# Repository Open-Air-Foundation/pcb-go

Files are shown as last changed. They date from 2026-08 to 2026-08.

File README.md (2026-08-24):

# AirGradient GO — Hardware

> KiCad hardware design files for the AirGradient GO, a portable battery-powered air quality monitor.

<!-- ![AirGradient GO](graphics/airgradient Final-02.png) -->

## Overview

AirGradient GO is a handheld air quality monitor. It measures particulate matter (Sensirion SPS30), CO₂ (Senseair S12), VOC/NOx (SGP41), temperature and humidity (SHT4x), and barometric pressure (DPS368), with an accelerometer (LIS2DH12) for motion detection and a GPS receiver (TAU1113) for location. Readings are shown on a 2.13″ black-and-white e-paper display with RGB LED indicators and capacitive touch controls. The device runs on a 505060 Li-Po pouch cell charged over USB-C.

This repository contains the complete electronics design: schematics, PCB layouts, shared component libraries, and production outputs for all four boards.

## Boards in this repository

| Board | Directory | Latest production set | Layers | Description |
|---|---|---|---|---|
| Main board | `PCB/airgradient-go-main/` | v1.0 | 4 | MCU, power/charging, sensors, storage |
| LED + touch controller | `PCB/led-touch/` | AG-GO-LED v1.0 | 2 | RGB LEDs, LED driver, and capacitive-touch controller; mates with the touch-pad board and mechanically holds the e-paper display (the display connector and control circuitry are on the main board) |
| Touch pad | `PCB/touch-pad/` | Touch_sensor v1.0 | 2 | Capacitive touch input board |
| SCD4x module | `PCB/scd4x-module/` | v0.1 | 2 | Optional CO₂ daughterboard (the standard configuration uses the on-board Senseair S12) |

> **Note:** v2.0 of the main board, touch pad, and LED + touch boards is currently in development.

## Key components (main board)

| Function | Part | Ref |
|---|---|---|
| MCU / Wi-Fi | ESP32-C5-MINI-1 | U4 |
| Battery charger | BQ25628 | U3 |
| Fuel gauge | BQ27427 | U8 |
| Buck-boost converter | TPS63802 | U2 |
| LDO | TPS7A0228 | U7 |
| Hardware watchdog | TPL5010 | U5 |
| NAND flash (512 Mb) | W25N512GVEIG | U1 |
| NAND flash (alternative footprint for U1) | ZDSD512MLGEAG | U14 |
| CO₂ sensor module | Senseair S12 | U17 |
| VOC/NOx sensor | SGP41 | U9 |
| Temperature/humidity sensor | SHT4x | U13 |
| Pressure sensor | DPS368 | U15 |
| Accelerometer | LIS2DH12 | U11 |
| GPS receiver | TAU1113 | U16 |
| I²C bus isolator | TMUX121 | U10 |
| I/O expander | TCA9536 | U18 |
| Buzzer | HYG-8503A | U12 |
| GPS antenna | GPS1003 | ANT1 |
| USB-C connector | GT-USB-7010ASV | USB1 |

PM sensing uses a Sensirion SPS30 module connected to the main board. CO₂ sensing is handled by the on-board Senseair S12; the SCD4x daughterboard is an optional alternative.

## Toolchain

- **KiCad 10** (file format 2026-03). All symbol, footprint, and 3D model libraries are bundled in `libraries/` and referenced project-relative through each board's `fp-lib-table` / `sym-lib-table` — the projects open without any extra library setup.
- **[Fabrication Toolkit](https://github.com/bennymeg/Fabrication-Toolkit)** plugin — generates the Gerber/BOM/CPL production sets (`fabrication-toolkit-options.json` per board).

## Repository structure

```
PCB/
├── airgradient-go-main/     # Main PCB (schematic, layout, production/)
├── led-touch/               # LED + touch-controller PCB (also holds the e-paper display)
├── touch-pad/               # Capacitive touch PCB
└── scd4x-module/            # Optional SCD4x CO₂ daughterboard
libraries/                   # Shared KiCad symbols, footprints, 3D models
graphics/                    # Logos and artwork
```

## Fabrication

Each board's `production/` directory holds the ready-to-order set for its latest released version: Gerber zip, BOM, designators, and pick-and-place positions in JLCPCB-compatible format (generated with Fabrication Toolkit). The main board is a 4-layer design; the display, touch, and SCD4x boards are 2-layer.

## BOM & sourcing

BOMs are exported alongside each production set (`production/*_bom.csv`) with LCSC part numbers for assembly at JLCPCB.

## Versioning & releases

Hardware revisions are tagged on this repository. Per-version release notes — chip-level changes, design history, and the matching production file set — are published on the [GitHub Releases](../../releases) page.

## Related repositories

<!-- TODO: add links to the firmware and enclosure repositories -->

## License

This is open-source hardware. The design files in this repository are licensed under the
[Creative Commons Attribution-ShareAlike 4.0 International (CC BY-SA 4.0)](https://creativecommons.org/licenses/by-sa/4.0/) license — see [LICENSE](LICENSE).

You are free to use, modify, and manufacture these designs, including commercially, provided you credit AirGradient and share derivative designs under the same license.

## Maintainers

AirGradient hardware team.

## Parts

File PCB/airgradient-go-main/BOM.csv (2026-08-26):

Reference | Qty | Value | DNP | Exclude from BOM | Exclude from Board | Footprint | Datasheet | LCSC Part
BT1 | 1 | Battery_Cell |  |  |  | AG-lib-oaf:AGGO-battery
C1,C3,C5,C7,C9,C10,C13,C15,C16,C24,C28,C39,C52,C56,C57,C59,C63,C70,C71,C72,C73,C74 | 22 | 0.1uF/25V |  |  |  | Capacitor_SMD:C_0402_1005Metric | https://lcsc.com/product-detail/Multilayer-Ceramic-Capacitors-MLCC-SMD-SMT_SAMSUNG_CL05A104KA5NNNC_100nF-104-10-25V_C100072.html | C100072
C2 | 1 | 47nF/25V |  |  |  | Capacitor_SMD:C_0402_1005Metric | https://lcsc.com/product-detail/Others_Guangdong-Fenghua-Advanced-Tech-0402B473K250NT_C285062.html | C285062
C4,C6,C11,C22,C60,C65 | 6 | 10uF/25V |  |  |  | Capacitor_SMD:C_0603_1608Metric | https://lcsc.com/product-detail/Multilayer-Ceramic-Capacitors-MLCC-SMD-SMT_SAMSUNG_CL10A106MA8NRNC_10uF-106-20-25V_C96446.html | C96446
C8,C45,C48 | 3 | 4.7uF/25V |  |  |  | Capacitor_SMD:C_0402_1005Metric |  | C6119795
C12,C36,C37,C38 | 4 | 22uF/25V |  |  |  | Capacitor_SMD:C_0805_2012Metric | https://lcsc.com/product-detail/Multilayer-Ceramic-Capacitors-MLCC-SMD-SMT_Samsung-Electro-Mechanics-CL21A226MAYNNNE_C602037.html | C602037
C17 | 1 | 0.1uF/10V |  |  |  | Capacitor_SMD:C_0402_1005Metric | https://lcsc.com | C315248
C19,C26,C29,C30,C35,C40,C41,C42,C43,C44,C46,C47,C49,C50,C51,C53,C54,C55,C58,C64,C66,C67,C68 | 23 | 1uF/50V |  |  |  | Capacitor_SMD:C_0402_1005Metric | https://lcsc.com/product-detail/Multilayer-Ceramic-Capacitors-MLCC-SMD-SMT_SAMSUNG_CL05A105KO5NNNC_1uF-105-10-16V_C29266.html | C7500380
C20 | 1 | 47uF/25V |  |  |  | Capacitor_SMD:C_1206_3216Metric | https://lcsc.com/product-detail/Multilayer-Ceramic-Capacitors-MLCC-SMD-SMT_Murata-Electronics-GRM31CR61E476ME44L_C403725.html | C403725
C21 | 1 | 22uF/10V |  |  |  | Capacitor_SMD:C_0402_1005Metric | https://lcsc.com | C315248
C27 | 1 | 0.47uF/25V |  |  |  | Capacitor_SMD:C_0402_1005Metric | https://lcsc.com/product-detail/Multilayer-Ceramic-Capacitors-MLCC-SMD-SMT_SAMSUNG_CL05A105KO5NNNC_1uF-105-10-16V_C29266.html | C7500380
C33 | 1 | 500pF/50V |  |  |  | Capacitor_SMD:C_0603_1608Metric | https://lcsc.com/product-detail/Multilayer-Ceramic-Capacitors-MLCC-SMD-SMT_500pF-501-10-50V_C1624.html | C1624
C69 | 1 | 0.1uF/16V |  |  |  | Capacitor_SMD:C_0402_1005Metric | https://lcsc.com/product-detail/Multilayer-Ceramic-Capacitors-MLCC-SMD-SMT_SAMSUNG_CL05B104KO5NNNC_100nF-104-10-16V_C1525.html | C1525
CN3,CN4,CN5 | 3 | SM05B-SRSS-TB (LF)(SN) |  |  |  | easyeda2kicad-oaf:CONN-SMD_SM05B-SRSS-TB-LF-SN | https://lcsc.com/product-detail/Connectors_JST_SM05B-SRSS-TB-LF-SN_SM05B-SRSS-TB-LF-SN_C136657.html | C136657
D3,D4,D5 | 3 | PMEG3005EL,315 |  |  |  | easyeda2kicad-oaf:SOD-882_L1.0-W0.6-RD | https://lcsc.com/product-detail/Schottky-Barrier-Diodes-SBD_Nexperia_PMEG3005EL-315_Nexperia-PMEG3005EL-315_C282565.html | C282565
F1 | 1 | BSMD1206-075-6V |  |  |  | easyeda2kicad-oaf:F1206 | https://lcsc.com/product-detail/PTC-Resettable-Fuses_BHFUSE-BSMD1206-075-6V_C883127.html | C883127
FPC1 | 1 | FPC 0.5-24P LTH2.0 |  |  |  | easyeda2kicad-oaf:FPC-SMD_FPC-0.5-24P-LTH2.0 |  | C6081230
L1 | 1 | 252012CDMCDDS-1R0MC |  |  |  | easyeda2kicad-oaf:IND-SMD_L2.5-W2.0 | https://lcsc.com/product-detail/New-Arrivals_Sumida-252012CDMCDDS-1R0MC_C492725.html | C492725
L2 | 1 | XGL4020-471MEC |  |  |  | easyeda2kicad-oaf:IND-SMD_L4.0-W4.0_XGL4020 |  | C5837785
L3 | 1 | XRTC201210S100MBCA |  |  |  | easyeda2kicad-oaf:L0805 |  | C39846618
LED1,LED2,LED3,LED4 | 4 | TJ-S1608SW6TDSLCCYRGB-A5 |  |  |  | easyeda2kicad-oaf:LED-ARRAY-SMD_4P-L1.6-W0.8-BL-FD |  | C5356078
NTC1 | 1 | KNTC0805/10KF3950 |  |  |  | easyeda2kicad-oaf:R0805 |  | C2892549
NTC2 | 1 | NCP15XH103F03RC |  |  |  | easyeda2kicad-oaf:R0402 | https://lcsc.com/product-detail/NTC-Thermistors_muRata_NCP15XH103F03RC_NTCThermistor-10kR-1_C77131.html | C77131
Q1 | 1 | SIA445EDJ-T1-GE3 |  |  |  | easyeda2kicad-oaf:SC-70-6L_L2.0-W2.0-P0.65-BL | https://lcsc.com/product-detail/MOSFET_VISHAY_SIA445EDJ-T1-GE3_SIA445EDJ-T1-GE3_C144959.html | C144959
Q2 | 1 | ZVN4106FTA_C508255 |  |  |  | easyeda2kicad-oaf:SOT-23-3_L2.9-W1.3-P1.90-LS2.4-BR | https://lcsc.com/product-detail/MOSFET_Diodes-Incorporated-ZVN4106FTA_C508255.html | C508255
Q3 | 1 | CSD83325L |  |  |  | easyeda2kicad-oaf:PICOSTAR-6_L2.2-W1.1-R2-C3-P0.65-BL |  | C2860700
Q4 | 1 | SS8050-G |  |  |  | easyeda2kicad-oaf:SOT-23-3_L2.9-W1.3-P1.90-LS2.4-BR | https://lcsc.com/product-detail/Transistors-NPN-PNP_SS8050-L-120-200_C164886.html | C164886
Q5 | 1 | SI1308EDL |  |  |  | easyeda2kicad-oaf:SOT-323-3_L2.0-W1.3-P1.30-LS2.1-BR |  | C7603347
R1,R2,R3,R4,R14,R29,R31,R33,R38,R39,R40,R44,R46,R59 | 14 | 100K |  |  |  | Resistor_SMD:R_0402_1005Metric | https://lcsc.com/product-detail/Chip-Resistor-Surface-Mount_100KR-1003-1_C60491.html,https://lcsc.com/product-detail/Others_Huaxin-S-T-MR04X1002FTL_C327797.html | C327797,C60491
R5,R12 | 2 | 200R |  |  |  | Resistor_SMD:R_0402_1005Metric
R6,R9 | 2 | 10R |  |  |  | Resistor_SMD:R_0402_1005Metric | https://lcsc.com/product-detail/Chip-Resistor-Surface-Mount_1KR-1001-1_C106235.html | C106235
R7,R11,R49 | 3 | 5.1K |  |  |  | Resistor_SMD:R_0402_1005Metric | https://lcsc.com/product-detail/Chip-Resistor-Surface-Mount_5-1KR-5101-1_C105872.html | C105872
R8 | 1 | 5mR 1%/1W |  |  |  | Resistor_SMD:R_1206_3216Metric
R10,R26,R30,R36,R54,R55,R56,R57,R58 | 9 | 10K |  |  |  | Resistor_SMD:R_0402_1005Metric | https://lcsc.com/product-detail/Others_Huaxin-S-T-MR04X1002FTL_C327797.html | C327797
R13 | 1 | 2K |  |  |  | Resistor_SMD:R_0402_1005Metric | https://lcsc.com/product-detail/Chip-Resistor-Surface-Mount_1KR-1001-1_C106235.html | C106235
R15 | 1 | 15K |  |  |  | Resistor_SMD:R_0402_1005Metric | https://lcsc.com/product-detail/Chip-Resistor-Surface-Mount-UniOhm_15KR-1502-1_C25756.html | C25756
R16 | 1 | 20K |  |  |  | Resistor_SMD:R_0402_1005Metric | https://lcsc.com/product-detail/Chip-Resistor-Surface-Mount_20KR-2002-1_C93942.html | C93942
R17,R20,R23 | 3 | 1K |  |  |  | Resistor_SMD:R_0402_1005Metric | https://lcsc.com/product-detail/Chip-Resistor-Surface-Mount_1KR-1001-1_C106235.html | C106235
R18 | 1 | 4.12K |  |  |  | Resistor_SMD:R_0402_1005Metric | https://lcsc.com/product-detail/Others_YAGEO-RC0402FR-074K12L_C327340.html | C327340
R19 | 1 | 17.33K |  |  |  | Resistor_SMD:R_0402_1005Metric |  | C851231
R21 | 1 | 2.49K |  |  |  | Resistor_SMD:R_0402_1005Metric | https://lcsc.com/product-detail/Chip-Resistor-Surface-Mount-UniOhm_2-49KR-2491-1_C25884.html | C25884
R22 | 1 | 475K |  |  |  | Resistor_SMD:R_0402_1005Metric |  | C5713272
R24 | 1 | 91K |  |  |  | Resistor_SMD:R_0402_1005Metric | https://lcsc.com/product-detail/Others_YAGEO-RC0402FR-0791KL_C327323.html | C327323
R25 | 1 | 51K |  |  |  | Resistor_SMD:R_0402_1005Metric | https://lcsc.com/product-detail/Chip-Resistor-Surface-Mount_51KR-5102-1_C107229.html | C107229
R27,R28,R50,R51,R52,R53 | 6 | 22R |  |  |  | Resistor_SMD:R_0402_1005Metric | https://lcsc.com/product-detail/Chip-Resistor-Surface-Mount_22R-22R0-1_C114765.html | C114765
R32 | 1 | 50mR |  |  |  | Resistor_SMD:R_0805_2012Metric | https://lcsc.com/product-detail/Chip-Resistor-Surface-Mount_0R-0R0-1_C106231.html | C106231
R35 | 1 | 470mR |  |  |  | Resistor_SMD:R_0805_2012Metric | https://lcsc.com/product-detail/Chip-Resistor-Surface-Mount_0R-0R0-1_C106231.html | C106231
R41 | 1 | 4.7R |  |  |  | Resistor_SMD:R_0402_1005Metric |  | C2909356
R42 | 1 | 1M |  |  |  | Resistor_SMD:R_0402_1005Metric | https://lcsc.com/product-detail/Chip-Resistor-Surface-Mount_1MR-1004-1_C138033.html | C138033
R43 | 1 | 2.2R |  |  |  | Resistor_SMD:R_0402_1005Metric | https://lcsc.com/product-detail/Chip-Resistor-Surface-Mount-UniOhm_2-2R-2R20-1_C25101.html | C25101
R45,R47 | 2 | 0R |  |  |  | Resistor_SMD:R_0402_1005Metric | https://lcsc.com/product-detail/Chip-Resistor-Surface-Mount_0R-0R0-1_C106231.html | C106231
SW1,SW2 | 2 | TS-1091C-A1B3-D2 |  |  |  | easyeda2kicad-oaf:KEY-SMD_3P-L5.5-W3.8-P3.00 |  | C2874581
TF1 | 1 | TF-CARD XG8P H1.5 |  |  |  | easyeda2kicad-oaf:TF-SMD_TF-CARD-XG8P-H1.5 |  | C7529392
U1 | 1 | W25N512GVEIG |  |  |  | easyeda2kicad-oaf:WSON-8_L8.0-W6.0-P1.27-TL-1 |  | C3024446
U3 | 1 | BQ27742YZFR-G1 |  |  |  | easyeda2kicad-oaf:DSBGA-15_L2.6-W2.0-R5-C3-P0.50-BL |  | C2842397
U4 | 1 | ESP32-C5-MINI-1 |  |  |  | Esparessif-oaf:ESP32-C5-MINI-1 | https://documentation.espressif.com/esp32-c5-mini-1_datasheet_en.pdf
U5 | 1 | BQ25628RYKR |  |  |  | easyeda2kicad-oaf:WQFN-18_L3.0-W2.5-P0.40-TL |  | C6055599
U6 | 1 | HYG-8503A |  |  |  | easyeda2kicad-oaf:BUZ-SMD_4P-L8.5-W8.5-P8.50-BR |  | C7544813
U7 | 1 | TPL5010DDCR |  |  |  | easyeda2kicad-oaf:SOT-23-6_L2.9-W1.6-P0.95-LS2.8-BR | https://lcsc.com/product-detail/Timer_Texas-Instruments-Texas-Instruments-TPL5010DDCR_C473912.html | C473912
U8 | 1 | TPS63802DLAR |  |  |  | easyeda2kicad-oaf:VSON-10_L3.0-W2.0-P0.50-TL |  | C2845237
U9 | 1 | TPS7A0228DQNR |  |  |  | easyeda2kicad-oaf:X2SON-4_L1.0-W1.0-P0.65-TL-EP |  | C5220175
U13 | 1 | SPL07-003 |  |  |  | easyeda2kicad-oaf:LGA-10_L2.0-W2.0-P0.50-BL |  | C3253727
U14 | 1 | LIS2DH12TR |  |  |  | easyeda2kicad-oaf:LGA-12_L2.0-W2.0-P0.50-BL | https://lcsc.com/product-detail/Motion-Sensors-Accelerometers_STMicroelectronics_LIS2DH12TR_STMicroelectronics-LIS2DH12TR_C110926.html | C110926
U15 | 1 | TMUX121NKGR_C22428404 |  |  |  | easyeda2kicad-oaf:UQFN-10_L1.8-W1.4-P0.40-BL |  | C22428404
U17 | 1 | TCA6408ARGT |  |  |  | Package_DFN_QFN:VQFN-16-1EP_3x3mm_P0.5mm_EP1.45x1.45mm | https://www.ti.com/lit/gpn/tca6408a
U18 | 1 | TAU1113 |  |  |  | RF_GPS-oaf:TAU1113 | https://docs.datagnss.com/rtk-board/files/T-5-2208-TAU1113%20Datasheet-V1.4.pdf
U19 | 1 | LM66200DRLR |  |  |  | easyeda2kicad-oaf:SOT-583-8_L2.1-W1.2-P0.50-LS1.6-BL |  | C3235556
U20 | 1 | LP5036 |  |  |  | Package_DFN_QFN:VQFN-46-1EP_5x6mm_P0.4mm_EP2.8x3.8mm | http://www.ti.com/lit/ds/symlink/lp5036.pdf
USB1 | 1 | GT-USB-7010ASV |  |  |  | easyeda2kicad-oaf:USB-C-SMD_G-SWITCH_GT-USB-7010ASV |  | C2988369

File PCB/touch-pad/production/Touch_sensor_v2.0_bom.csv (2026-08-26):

Designator | Footprint | Quantity | Value | LCSC Part #
C42 | 0402 | 1 | 0.1uF/25V | C100072
CN1 | CONN-SMD_HCZZ0032-5 | 1 | HCZZ0032-5 | C7433426
R38 | 0402 | 1 | 100K | C60491
T1, T2, T3 | tourch_pad | 3 | ~
TP1 | TestPoint_Pad_D1.5mm | 1 | TestPoint
U11 | TDFN-8_L3.0-W2.0-P0.50-BL-EP | 1 | CAP1203-1-AC3-TR | C2652075

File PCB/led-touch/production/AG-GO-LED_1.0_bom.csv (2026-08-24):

Designator | Footprint | Quantity | Value | LCSC Part #
_3, _2, |  | 3
C1 | 0805 | 1 | 22uF/25V | C602037
C2, C3 | 0402 | 2 | 0.1uF/16V | C1525
C4 | 0402 | 1 | 1uF/50V | C7500380
CN1 | CONN-SMD_SM05B-SRSS-TB-LF-SN | 1 | SM05B-SRSS-TB (LF)(SN) | C136657
FPC1 | FPC-SMD_6P-P0.50_0.5-6PQFHY-H1.0119 | 1 | 0.5-6PQFHY-H1.0 119 | C2858296
LED1, LED10, LED2, LED3, LED4, LED5, LED6, LED7, LED8, LED9 | LED-ARRAY-SMD_4P-L1.6-W0.8-BL-FD | 10 | TJ-S1608SW6TDSLCCYRGB-A5 | C5356078
LED25, LED26 | LED-SMD_L2.8-W1.2-RD | 2 | 99-213UMC/3640661/TR8-T | C181869
R1 | 0402 | 1 | 5.1K | C105872
R2 | 0402 | 1 | 100K | C60491
R3 | 0402 | 1 | RC0402FR-070RL | C106231
T1 | touch-pad-go | 1 | touch-left
U1 | TDFN-8_L3.0-W2.0-P0.50-BL-EP | 1 | CAP1203-1-AC3-TR | C2652075
U2 | VQFN-46-1EP_5x6mm_P0.4mm_EP2.8x3.8mm | 1 | LP5036

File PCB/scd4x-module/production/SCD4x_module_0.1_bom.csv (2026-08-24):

Designator | Footprint | Quantity | Value | LCSC Part #
_8, _7, _6, _4, _3, _2 |  | 6
_5, | 0faea2d4-577a-4ea1-81af-0a26aae559f2 | 2
U1 | Sensirion_SCD4x-1EP_10.1x10.1mm_P1.25mm_EP4.8x4.8mm | 1 | SCD43-D-R2

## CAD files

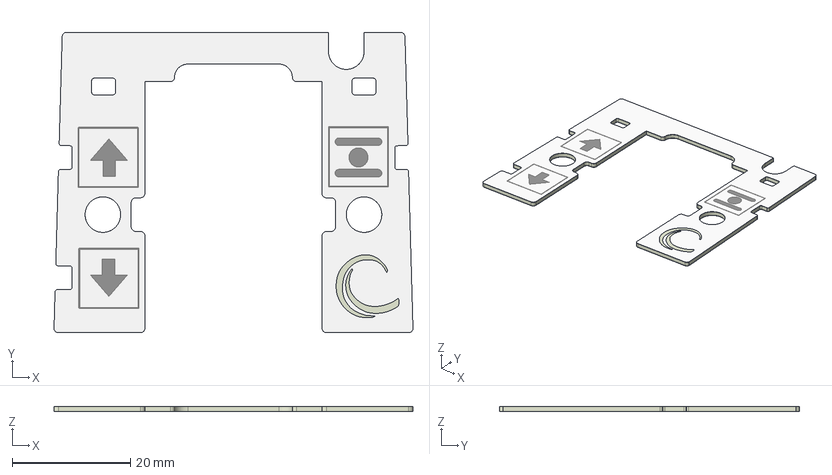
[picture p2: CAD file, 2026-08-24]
PCB/touch-pad/touch_pad.step
60.6 x 50.7 x 1.06 mm
touch-pad-left_silkscreen x 2
touch-pad-left_soldermask x 2
touch-pad-left_PCB

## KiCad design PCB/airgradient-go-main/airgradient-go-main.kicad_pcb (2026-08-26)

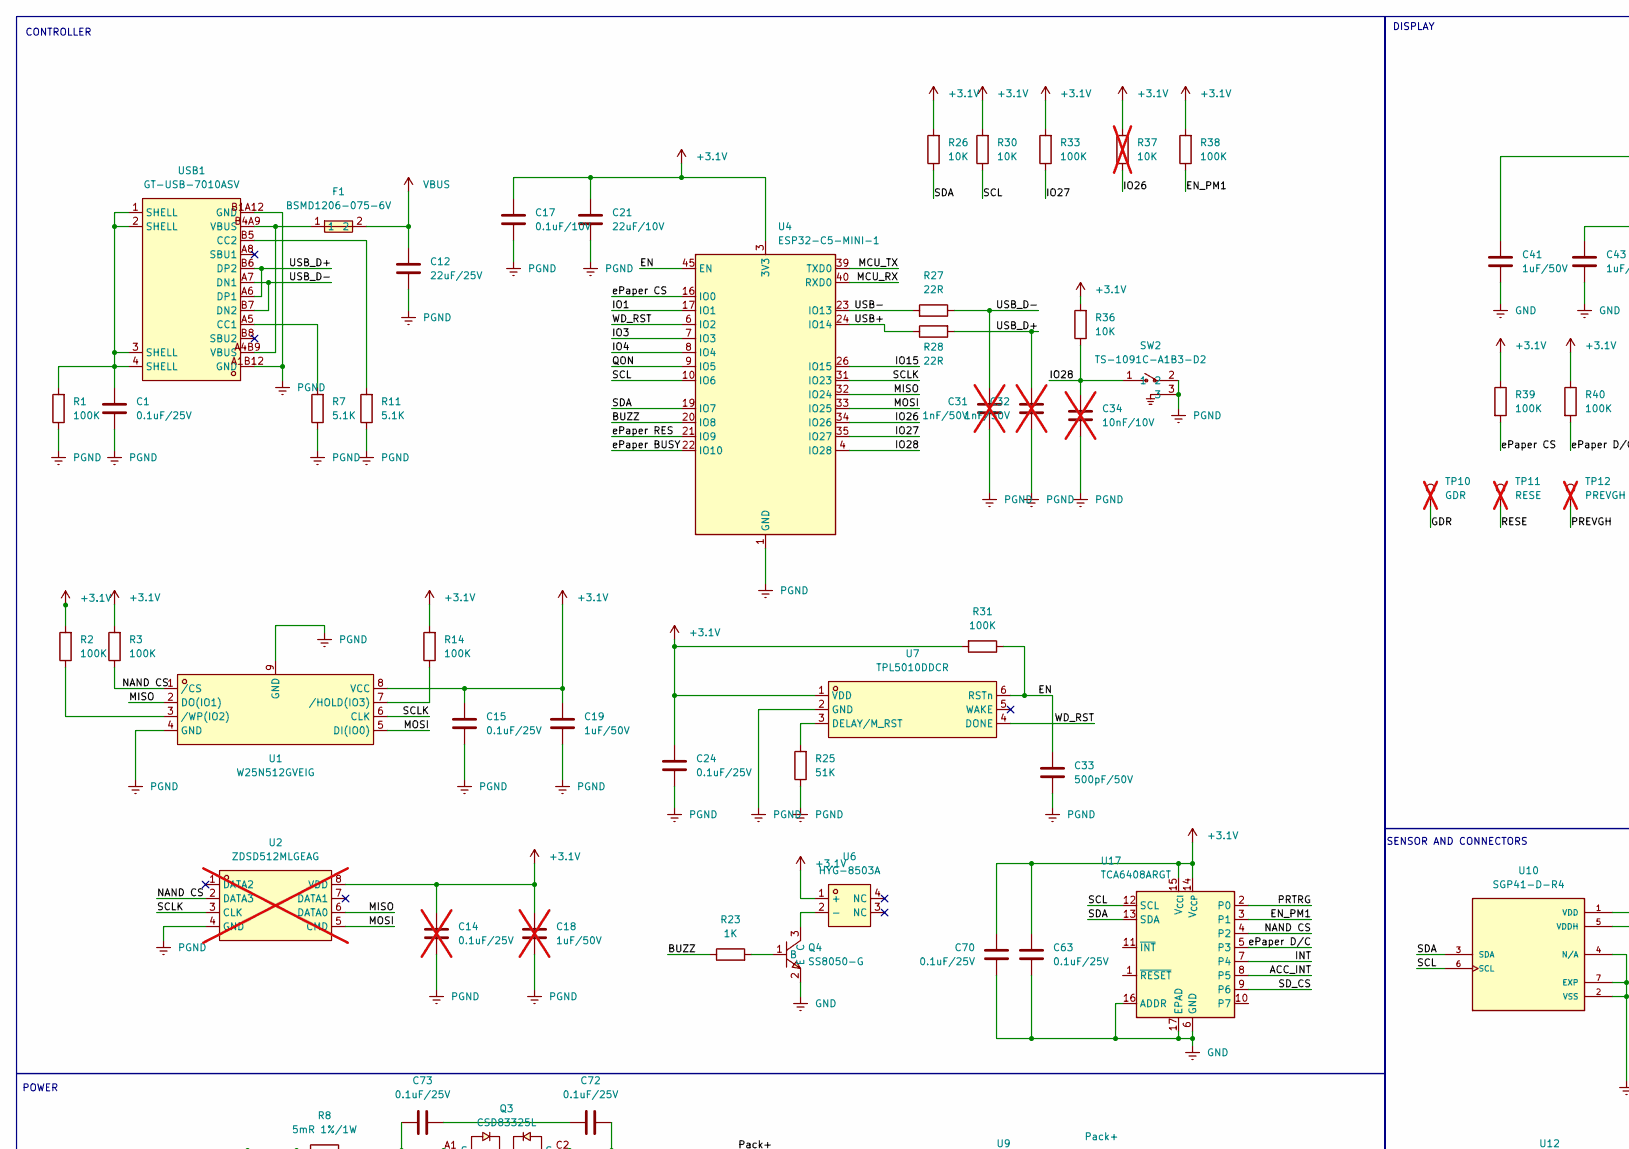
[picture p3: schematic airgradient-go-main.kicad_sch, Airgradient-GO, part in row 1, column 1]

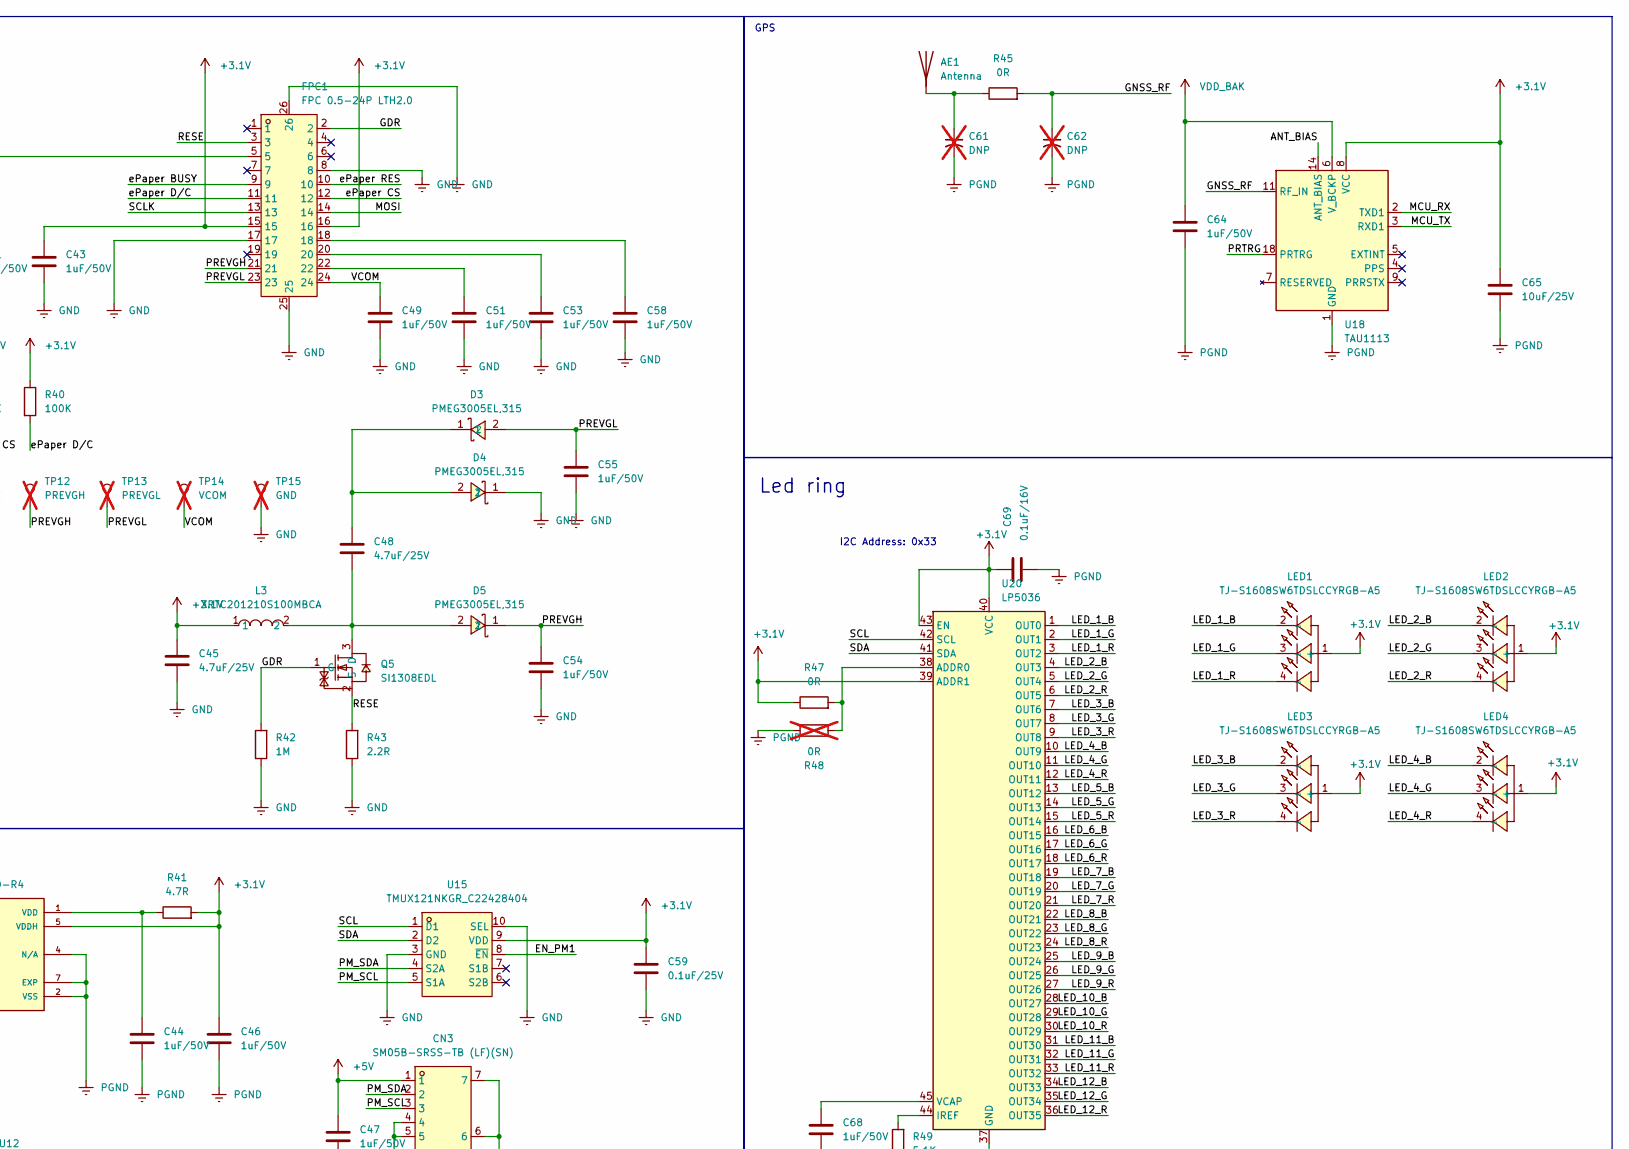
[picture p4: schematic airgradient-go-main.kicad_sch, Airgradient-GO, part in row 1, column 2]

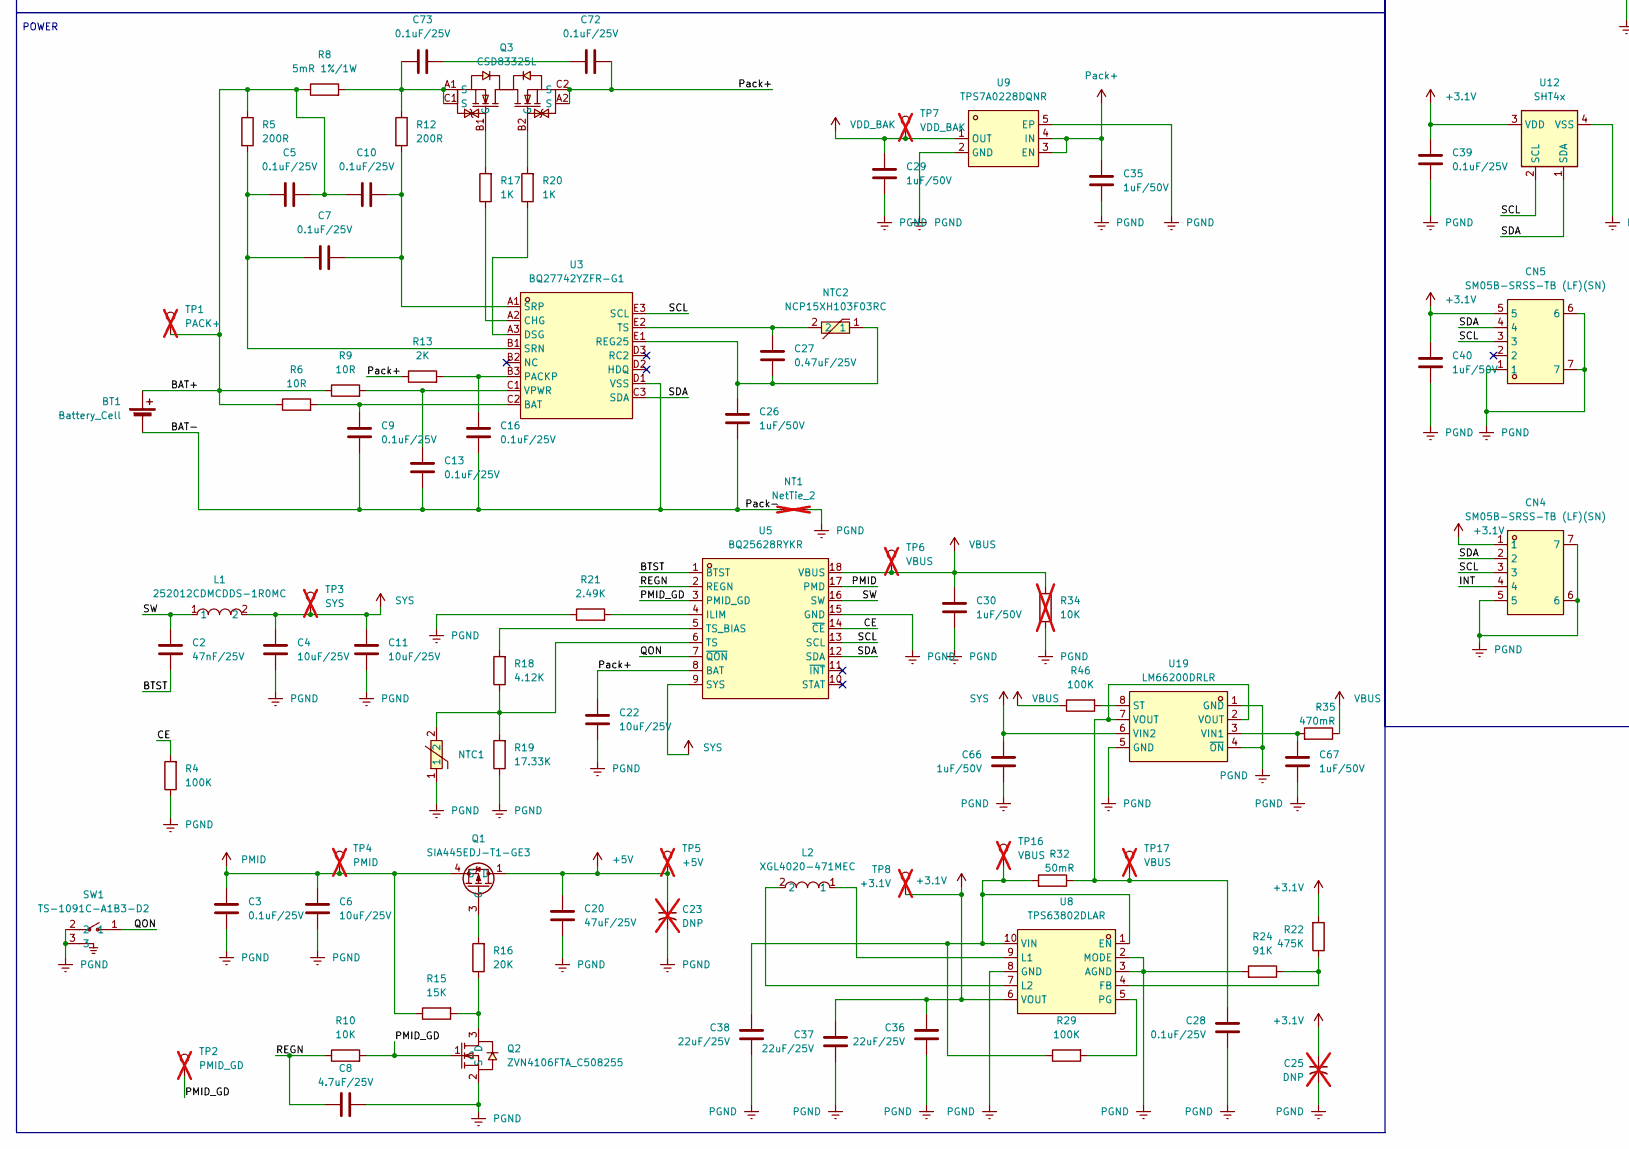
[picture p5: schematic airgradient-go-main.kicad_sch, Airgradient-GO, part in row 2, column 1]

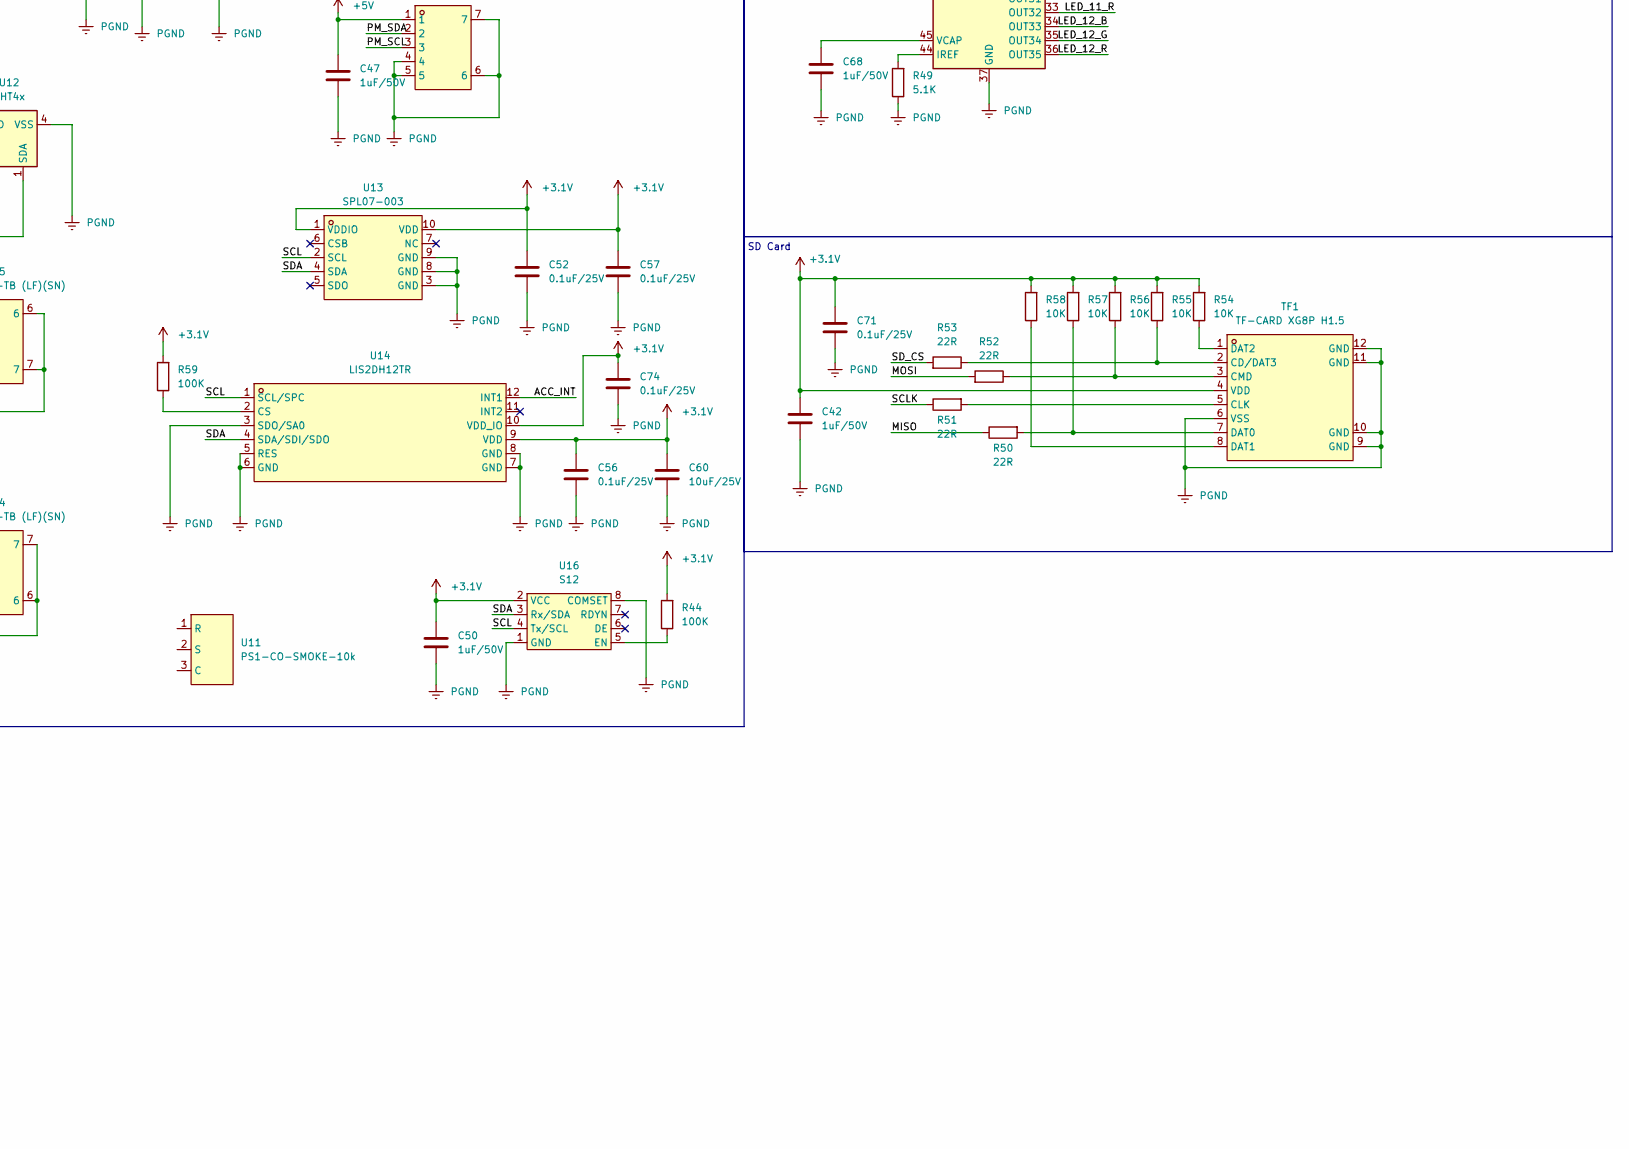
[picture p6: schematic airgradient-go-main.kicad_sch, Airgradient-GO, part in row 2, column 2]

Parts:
AE1: Antenna; CA-G01
BT1: Battery_Cell; AGGO-battery
C1, C3, C5, C7, C9, C10, C13, C15, C16, C24, C28, C39, C52, C56, C57, C59, C63, C70, C71, C72, C73, C74: 0.1uF/25V; C_0402_1005Metric; LCSC Part C100072
C2: 47nF/25V; C_0402_1005Metric; LCSC Part C285062
C4, C6, C11, C22, C60, C65: 10uF/25V; C_0603_1608Metric; LCSC Part C96446
C8, C45, C48: 4.7uF/25V; C_0402_1005Metric; LCSC Part C6119795
C12, C36, C37, C38: 22uF/25V; C_0805_2012Metric; LCSC Part C602037
C14: 0.1uF/25V; C_0402_1005Metric; LCSC Part C100072; not fitted
C17: 0.1uF/10V; C_0402_1005Metric; LCSC Part C315248
C18: 1uF/50V; C_0402_1005Metric; LCSC Part C7500380; not fitted
C19, C26, C29, C30, C35, C40, C41, C42, C43, C44, C46, C47, C49, C50, C51, C53, C54, C55, C58, C64, C66, C67, C68: 1uF/50V; C_0402_1005Metric; LCSC Part C7500380
C20: 47uF/25V; C_1206_3216Metric; LCSC Part C403725
C21: 22uF/10V; C_0402_1005Metric; LCSC Part C315248
C23, C25: DNP; C_1206_3216Metric; not fitted
C27: 0.47uF/25V; C_0402_1005Metric; LCSC Part C7500380
C31, C32: 1nF/50V; C_0402_1005Metric; LCSC Part C106205; not fitted
C33: 500pF/50V; C_0603_1608Metric; LCSC Part C1624
C34: 10nF/10V; C_0402_1005Metric; LCSC Part C541371; not fitted
C61, C62: DNP; C_0402_1005Metric; not fitted
C69: 0.1uF/16V; C_0402_1005Metric; LCSC Part C1525
CN3, CN4, CN5: SM05B-SRSS-TB (LF)(SN); CONN-SMD_SM05B-SRSS-TB-LF-SN; LCSC Part C136657
D3, D4, D5: PMEG3005EL,315; SOD-882_L1.0-W0.6-RD; LCSC Part C282565
F1: BSMD1206-075-6V; F1206; LCSC Part C883127
FPC1: FPC 0.5-24P LTH2.0; FPC-SMD_FPC-0.5-24P-LTH2.0; LCSC Part C6081230
L1: 252012CDMCDDS-1R0MC; IND-SMD_L2.5-W2.0; LCSC Part C492725
L2: XGL4020-471MEC; IND-SMD_L4.0-W4.0_XGL4020; LCSC Part C5837785
L3: XRTC201210S100MBCA; L0805; LCSC Part C39846618
LED1, LED2, LED3, LED4: TJ-S1608SW6TDSLCCYRGB-A5; LED-ARRAY-SMD_4P-L1.6-W0.8-BL-FD; LCSC Part C5356078
NT1: NetTie_2; NetTie-2_SMD_Pad0.5mm; not fitted
NTC1: KNTC0805/10KF3950; R0805; LCSC Part C2892549
NTC2: NCP15XH103F03RC; R0402; LCSC Part C77131
Q1: SIA445EDJ-T1-GE3; SC-70-6L_L2.0-W2.0-P0.65-BL; LCSC Part C144959
Q2: ZVN4106FTA_C508255; SOT-23-3_L2.9-W1.3-P1.90-LS2.4-BR; LCSC Part C508255
Q3: CSD83325L; PICOSTAR-6_L2.2-W1.1-R2-C3-P0.65-BL; LCSC Part C2860700
Q4: SS8050-G; SOT-23-3_L2.9-W1.3-P1.90-LS2.4-BR; LCSC Part C164886
Q5: SI1308EDL; SOT-323-3_L2.0-W1.3-P1.30-LS2.1-BR; LCSC Part C7603347
R1, R4, R29, R31, R39, R40, R46: 100K; R_0402_1005Metric; LCSC Part C60491
R2, R3, R14, R33, R38, R44, R59: 100K; R_0402_1005Metric; LCSC Part C327797
R5, R12: 200R; R_0402_1005Metric
R6, R9: 10R; R_0402_1005Metric; LCSC Part C106235
R7, R11, R49: 5.1K; R_0402_1005Metric; LCSC Part C105872
R8: 5mR 1%/1W; R_1206_3216Metric
R10, R26, R30, R36, R54, R55, R56, R57, R58: 10K; R_0402_1005Metric; LCSC Part C327797
R13: 2K; R_0402_1005Metric; LCSC Part C106235
R15: 15K; R_0402_1005Metric; LCSC Part C25756
R16: 20K; R_0402_1005Metric; LCSC Part C93942
R17, R20, R23: 1K; R_0402_1005Metric; LCSC Part C106235
R18: 4.12K; R_0402_1005Metric; LCSC Part C327340
R19: 17.33K; R_0402_1005Metric; LCSC Part C851231
R21: 2.49K; R_0402_1005Metric; LCSC Part C25884
R22: 475K; R_0402_1005Metric; LCSC Part C5713272
R24: 91K; R_0402_1005Metric; LCSC Part C327323
R25: 51K; R_0402_1005Metric; LCSC Part C107229
R27, R28, R50, R51, R52, R53: 22R; R_0402_1005Metric; LCSC Part C114765
R32: 50mR; R_0805_2012Metric; LCSC Part C106231
R34, R37: 10K; R_0402_1005Metric; LCSC Part C327797; not fitted
R35: 470mR; R_0805_2012Metric; LCSC Part C106231
R41: 4.7R; R_0402_1005Metric; LCSC Part C2909356
R42: 1M; R_0402_1005Metric; LCSC Part C138033
R43: 2.2R; R_0402_1005Metric; LCSC Part C25101
R45, R47: 0R; R_0402_1005Metric; LCSC Part C106231
R48: 0R; R_0402_1005Metric; LCSC Part C106231; not fitted
SW1, SW2: TS-1091C-A1B3-D2; KEY-SMD_3P-L5.5-W3.8-P3.00; LCSC Part C2874581
TF1: TF-CARD XG8P H1.5; TF-SMD_TF-CARD-XG8P-H1.5; LCSC Part C7529392
TP1: PACK+; TestPoint_Pad_D1.0mm; not fitted
TP2: PMID_GD; TestPoint_Pad_D1.0mm; not fitted
TP3: SYS; TestPoint_Pad_D1.0mm; not fitted
TP4: PMID; TestPoint_Pad_D1.0mm; not fitted
TP5: +5V; TestPoint_Keystone_5019_Miniature; not fitted
TP6, TP16, TP17: VBUS; TestPoint_Pad_D1.0mm; not fitted
TP7: VDD_BAK; TestPoint_Pad_D1.0mm; not fitted
TP8: +3.1V; TestPoint_Keystone_5019_Miniature; not fitted
TP10: GDR; TestPoint_Pad_D1.0mm; not fitted
TP11: RESE; TestPoint_Pad_D1.0mm; not fitted
TP12: PREVGH; TestPoint_Pad_D1.0mm; not fitted
TP13: PREVGL; TestPoint_Pad_D1.0mm; not fitted
TP14: VCOM; TestPoint_Pad_D1.0mm; not fitted
TP15: GND; TestPoint_Pad_D1.0mm; not fitted
U1: W25N512GVEIG; WSON-8_L8.0-W6.0-P1.27-TL-1; LCSC Part C3024446
U2: ZDSD512MLGEAG; LGA-8_L8.0-W6.0-P1.27-TL; LCSC Part C22379765; not fitted
U3: BQ27742YZFR-G1; DSBGA-15_L2.6-W2.0-R5-C3-P0.50-BL; LCSC Part C2842397
U4: ESP32-C5-MINI-1
U5: BQ25628RYKR; WQFN-18_L3.0-W2.5-P0.40-TL; LCSC Part C6055599
U6: HYG-8503A; BUZ-SMD_4P-L8.5-W8.5-P8.50-BR; LCSC Part C7544813
U7: TPL5010DDCR; SOT-23-6_L2.9-W1.6-P0.95-LS2.8-BR; LCSC Part C473912
U8: TPS63802DLAR; VSON-10_L3.0-W2.0-P0.50-TL; LCSC Part C2845237
U9: TPS7A0228DQNR; X2SON-4_L1.0-W1.0-P0.65-TL-EP; LCSC Part C5220175
U10: SGP41-D-R4; XDCR_SGP41-D-R4; PARTREV 1.0
U11: PS1-CO-SMOKE-10k
U12: SHT4x; Sensirion_DFN-4_1.5x1.5mm_P0.8mm_SHT4x_NoCentralPad
U13: SPL07-003; LGA-10_L2.0-W2.0-P0.50-BL; LCSC Part C3253727
U14: LIS2DH12TR; LGA-12_L2.0-W2.0-P0.50-BL; LCSC Part C110926
U15: TMUX121NKGR_C22428404; UQFN-10_L1.8-W1.4-P0.40-BL; LCSC Part C22428404
U16: S12
U17: TCA6408ARGT; VQFN-16-1EP_3x3mm_P0.5mm_EP1.45x1.45mm
U18: TAU1113
U19: LM66200DRLR; SOT-583-8_L2.1-W1.2-P0.50-LS1.6-BL; LCSC Part C3235556
U20: LP5036; VQFN-46-1EP_5x6mm_P0.4mm_EP2.8x3.8mm
USB1: GT-USB-7010ASV; USB-C-SMD_G-SWITCH_GT-USB-7010ASV; LCSC Part C2988369

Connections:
+3.1V: C14.2, C15.2, C17.2, C18.2, C19.2, C21.2, C24.2, C25.1, C36.2, C37.2, C39.2, C40.2, C42.2, C43.2, C45.2, C46.2, C50.2, C52.2, C56.2, C57.2, C59.2, C60.2, C63.2, C65.2, C69.2, C70.2, C71.2, C74.2, CN4.1, CN5.5, FPC1.15, FPC1.16, L3.1, LED1.1 (+), LED2.1 (+), LED3.1 (+), LED4.1 (+), R2.2, R3.2, R14.2, R22.2, R26.2, R30.2, R31.2, R33.2, R36.2, R37.2, R38.2, R39.1, R40.1, R41.2, R44.2, R47.1, R54.2, R55.2, R56.2, R57.2, R58.2, R59.2, TF1.4 (VDD), TP8.1, U1.8 (VCC), U2.8 (VDD), U4.3 (3V3), U6.1 (+), U7.1 (VDD), U8.6 (VOUT), U10.5 (VDDH), U12.3 (VDD), U13.1 (VDDIO), U13.10 (VDD), U14.9 (VDD), U14.10 (VDD_IO), U15.9 (VDD), U16.2 (VCC), U17.14 (V_{CCP}), U17.15 (V_{CCI}), U18.8 (VCC), U20.39 (ADDR1), U20.40 (VCC), U20.43 (EN)
+5V: C20.2, C23.1, C47.2, CN3.1, Q1.1 (D), Q1.2 (D), Q1.5 (D), Q1.6 (D), Q1.8 (D), TP5.1
/ACC_INT: U14.12 (INT1), U17.8 (P5)
/ANT_BIAS: U18.14 (ANT_BIAS)
/BAT+: BT1.1 (+), C5.1, C10.2, R5.1, R6.1, R8.1, R9.1, TP1.1
/BAT-: BT1.2 (-), C9.2, C13.2, C16.2, C26.1, NT1.1, U3.D1 (VSS)
/BTST: C2.1, U5.1 (BTST)
/BUZZ: R23.1, U4.20 (IO8)
/CE: R4.2, U5.14 (~CE)
/EN: C33.2, R31.1, U4.45 (EN), U7.6 (RSTn)
/EN_PM1: R38.1, U15.8 (~EN), U17.3 (P1)
/GDR: FPC1.2, Q5.1 (G), R42.2, TP10.1
/GNSS_RF: C62.1, R45.2, U18.11 (RF_IN)
/INT: CN4.4, U17.7 (P4)
/IO1: U4.17 (IO1)
/IO3: U4.7 (IO3)
/IO4: U4.8 (IO4)
/IO15: U4.26 (IO15)
/IO26: R37.1, U4.34 (IO26)
/IO27: R33.1, U4.35 (IO27)
/IO28: C34.2, R36.1, SW2.1, U4.4 (IO28)
/LED_1_B: LED1.2 (-), U20.1 (OUT0)
/LED_1_G: LED1.3 (-), U20.2 (OUT1)
/LED_1_R: LED1.4 (-), U20.3 (OUT2)
/LED_2_B: LED2.2 (-), U20.4 (OUT3)
/LED_2_G: LED2.3 (-), U20.5 (OUT4)
/LED_2_R: LED2.4 (-), U20.6 (OUT5)
/LED_3_B: LED3.2 (-), U20.7 (OUT6)
/LED_3_G: LED3.3 (-), U20.8 (OUT7)
/LED_3_R: LED3.4 (-), U20.9 (OUT8)
/LED_4_B: LED4.2 (-), U20.10 (OUT9)
/LED_4_G: LED4.3 (-), U20.11 (OUT10)
/LED_4_R: LED4.4 (-), U20.12 (OUT11)
/LED_5_B: U20.13 (OUT12)
/LED_5_G: U20.14 (OUT13)
/LED_5_R: U20.15 (OUT14)
/LED_6_B: U20.16 (OUT15)
/LED_6_G: U20.17 (OUT16)
/LED_6_R: U20.18 (OUT17)
/LED_7_B: U20.19 (OUT18)
/LED_7_G: U20.20 (OUT19)
/LED_7_R: U20.21 (OUT20)
/LED_8_B: U20.22 (OUT21)
/LED_8_G: U20.23 (OUT22)
/LED_8_R: U20.24 (OUT23)
/LED_9_B: U20.25 (OUT24)
/LED_9_G: U20.26 (OUT25)
/LED_9_R: U20.27 (OUT26)
/LED_10_B: U20.28 (OUT27)
/LED_10_G: U20.29 (OUT28)
/LED_10_R: U20.30 (OUT29)
/LED_11_B: U20.31 (OUT30)
/LED_11_G: U20.32 (OUT31)
/LED_11_R: U20.33 (OUT32)
/LED_12_B: U20.34 (OUT33)
/LED_12_G: U20.35 (OUT34)
/LED_12_R: U20.36 (OUT35)
/MCU_RX: U4.40 (RXD0), U18.2 (TXD1)
/MCU_TX: U4.39 (TXD0), U18.3 (RXD1)
/MISO: R50.1, U1.2 (DO(IO1)), U2.6 (DATA0), U4.32 (IO24)
/MOSI: FPC1.14, R52.2, U1.5 (DI(IO0)), U2.5 (CMD), U4.33 (IO25)
/NAND CS: R3.1, U1.1 (/CS), U2.2 (DATA3), U17.4 (P2)
/PMID_GD: Q2.1 (G), R10.2, TP2.1, U5.3 (PMID_GD)
/PM_SCL: CN3.3, U15.5 (S1A)
/PM_SDA: CN3.2, U15.4 (S2A)
/PREVGH: C54.2, D5.1, FPC1.21, TP12.1
/PREVGL: C55.2, D3.2, FPC1.23, TP13.1
/PRTRG: U17.2 (P0), U18.18 (PRTRG)
/QON: SW1.1, U4.9 (IO5), U5.7 (~QON)
/REGN: C8.2, R10.1, U5.2 (REGN)
/RESE: FPC1.3, Q5.2 (S), R43.2, TP11.1
/SCL: CN4.3, CN5.3, R30.1, U3.E3 (SCL), U4.10 (IO6), U5.13 (SCL), U10.6 (SCL), U12.2 (SCL), U13.2 (SCL), U14.1 (SCL/SPC), U15.1 (D1), U16.4 (Tx/SCL), U17.12 (SCL), U20.42 (SCL)
/SCLK: FPC1.13, R51.1, U1.6 (CLK), U2.3 (CLK), U4.31 (IO23)
/SDA: CN4.2, CN5.4, R26.1, U3.C3 (SDA), U4.19 (IO7), U5.12 (SDA), U10.3 (SDA), U12.1 (SDA), U13.4 (SDA), U14.4 (SDA/SDI/SDO), U15.2 (D2), U16.3 (Rx/SDA), U17.13 (SDA), U20.41 (SDA)
/SD_CS: R53.2, U17.9 (P6)
/SW: C2.2, L1.1, U5.16 (SW)
/USB+: R28.1, U4.24 (IO14)
/USB-: R27.2, U4.23 (IO13)
/USB_D+: C32.2, R28.2, USB1.A6 (DP1), USB1.B6 (DP2)
/USB_D-: C31.2, R27.1, USB1.A7 (DN1), USB1.B7 (DN2)
/VCOM: C49.2, FPC1.24, TP14.1
/WD_RST: U4.6 (IO2), U7.4 (DONE)
/ePaper BUSY: FPC1.9, U4.22 (IO10)
/ePaper CS: FPC1.12, R39.2, U4.16 (IO0)
/ePaper D/C: FPC1.11, R40.2, U17.5 (P3)
/ePaper RES: FPC1.10, U4.21 (IO9)
unnamed: AE1.1 (A_1), C61.1, R45.1
unnamed: C1.2, R1.2, USB1.1 (SHELL), USB1.2 (SHELL), USB1.3 (SHELL), USB1.4 (SHELL)
unnamed: C28.2, R32.1, TP17.1, U19.2 (VOUT), U19.7 (VOUT)
unnamed: C41.2, FPC1.5
unnamed: C48.2, D3.1, D4.2
unnamed: C51.2, FPC1.22
unnamed: C53.2, FPC1.20
unnamed: C58.2, FPC1.18
unnamed: C72.2, C73.1
unnamed: C73.2, Q3.A1 (S), Q3.C1 (S), R8.2, R12.1
unnamed: F1.1, USB1.A4B9 (VBUS), USB1.B4A9 (VBUS)
unnamed: Q1.3 (G), R16.2
unnamed: Q2.3 (D), R15.2, R16.1
unnamed: Q3.B1 (G), R17.2
unnamed: Q3.B2 (G), R20.2
unnamed: Q4.1 (B), R23.2
unnamed: Q4.3 (C), U6.2 (-)
unnamed: C48.1, D5.2, L3.2, Q5.3 (D)
unnamed: R53.1, R55.1, TF1.2 (CD/DAT3)
unnamed: R51.2, TF1.5 (CLK)
unnamed: R52.1, R56.1, TF1.3 (CMD)
unnamed: R50.2, R57.1, TF1.7 (DAT0)
unnamed: R58.1, TF1.8 (DAT1)
unnamed: R54.1, TF1.1 (DAT2)
unnamed: R14.1, U1.7 (/HOLD(IO3))
unnamed: R2.1, U1.3 (/WP(IO2))
unnamed: C9.1, R6.2, U3.C2 (BAT)
unnamed: R17.1, U3.A2 (CHG)
unnamed: R20.1, U3.A3 (DSG)
unnamed: C16.1, R13.2, U3.B3 (PACKP)
unnamed: C26.2, C27.1, NTC2.1, U3.E1 (REG25)
unnamed: C5.2, C7.2, R5.2, U3.B1 (SRN)
unnamed: C7.1, C10.1, R12.2, U3.A1 (SRP)
unnamed: C27.2, NTC2.2, U3.E2 (TS)
unnamed: C13.1, R9.2, U3.C1 (VPWR)
unnamed: R21.2, U5.4 (ILIM)
unnamed: NTC1.2, R18.1, R19.2, U5.6 (TS)
unnamed: R18.2, U5.5 (TS_BIAS)
unnamed: R25.2, U7.3 (DELAY/M_RST)
unnamed: C38.2, R29.1, R32.2, TP16.1, U8.1 (EN), U8.10 (VIN)
unnamed: R22.1, R24.1, U8.4 (FB)
unnamed: L2.1, U8.9 (L1)
unnamed: L2.2, U8.7 (L2)
unnamed: R29.2, U8.5 (PG)
unnamed: C44.2, R41.1, U10.1 (VDD)
unnamed: R59.1, U14.2 (CS)
unnamed: R44.1, U16.5 (EN)
unnamed: R46.2, U19.8 (ST)
unnamed: C67.2, R35.2, U19.3 (VIN1)
unnamed: R47.2, R48.2, U20.38 (ADDR0)
unnamed: R49.2, U20.44 (IREF)
unnamed: C68.2, U20.45 (VCAP)
unnamed: R7.2, USB1.A5 (CC1)
unnamed: R11.2, USB1.B5 (CC2)
PMID: C3.2, C6.2, Q1.4 (S), Q1.7 (S), R15.1, TP4.1, U5.17 (PMD)
Pack+: C22.2, C35.2, C72.1, Q3.A2 (S), Q3.C2 (S), R13.1, U5.8 (BAT), U9.3 (EN), U9.4 (IN)
SYS: C4.2, C11.2, C66.2, L1.2, TP3.1, U5.9 (SYS), U19.6 (VIN2)
VBUS: C12.2, C30.2, F1.2, R34.2, R35.1, R46.1, TP6.1, U5.18 (VBUS)
VDD_BAK: C29.2, C64.2, TP7.1, U9.1 (OUT), U18.6 (V_BCKP)

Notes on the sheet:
DISPLAY
POWER
GPS
SENSOR AND CONNECTORS
Led ring
I2C Address: 0x33
CONTROLLER
SD Card

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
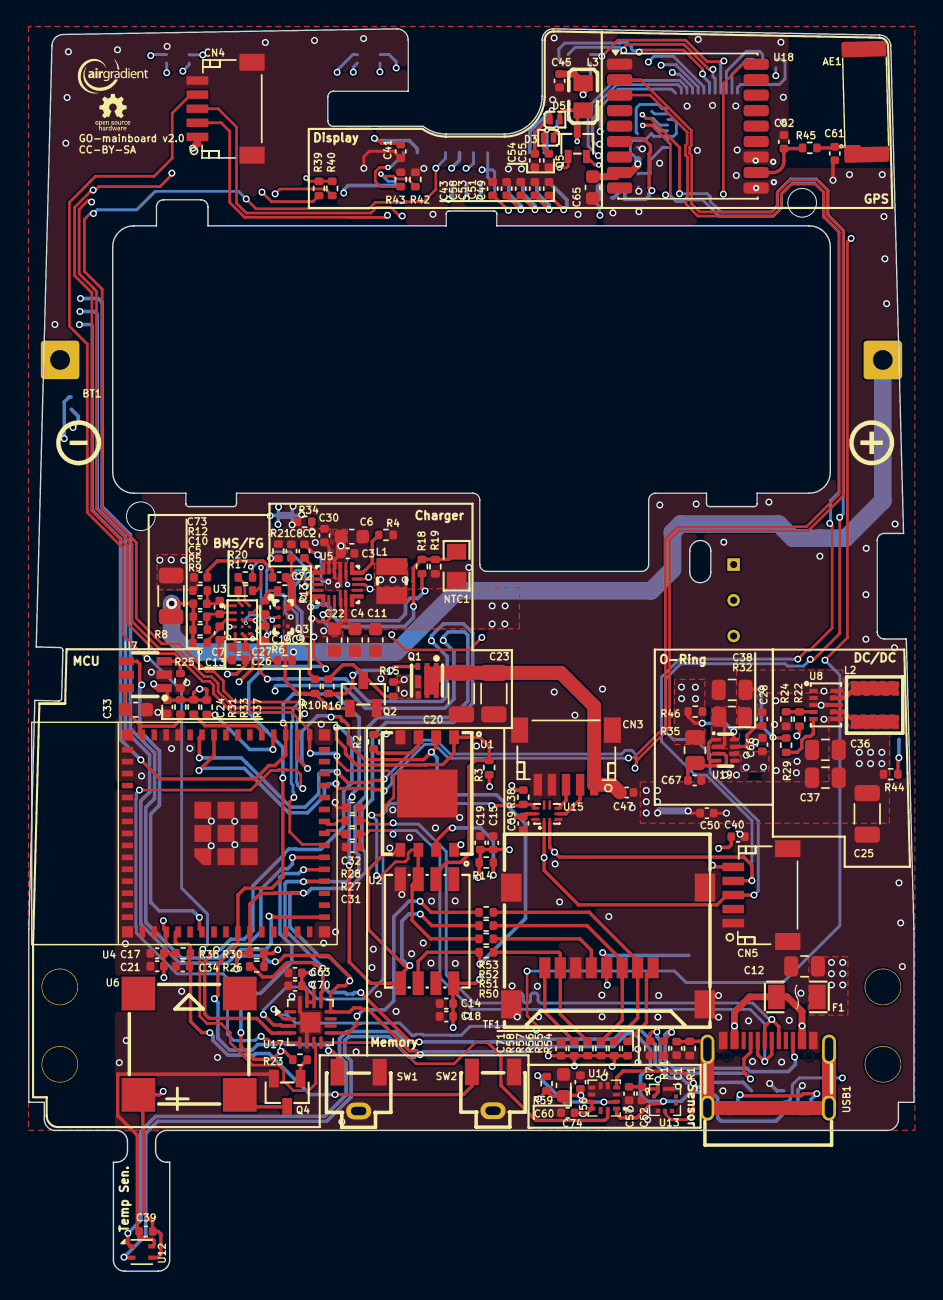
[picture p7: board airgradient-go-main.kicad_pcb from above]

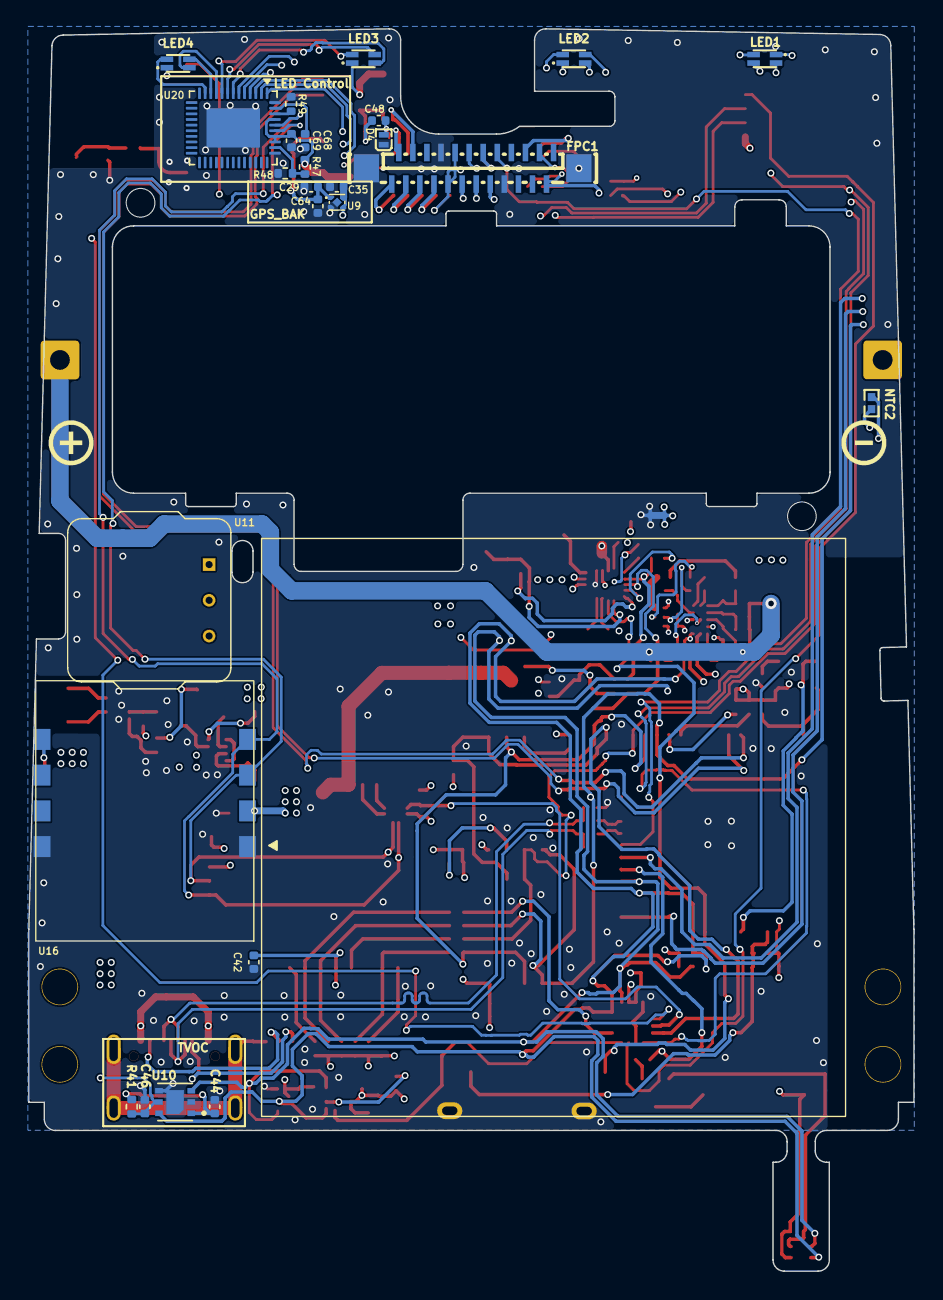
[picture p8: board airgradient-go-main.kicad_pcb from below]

Board: 4 copper layers, 62.9 x 88.3 mm, 182 parts (26 on the bottom side), 117 nets.

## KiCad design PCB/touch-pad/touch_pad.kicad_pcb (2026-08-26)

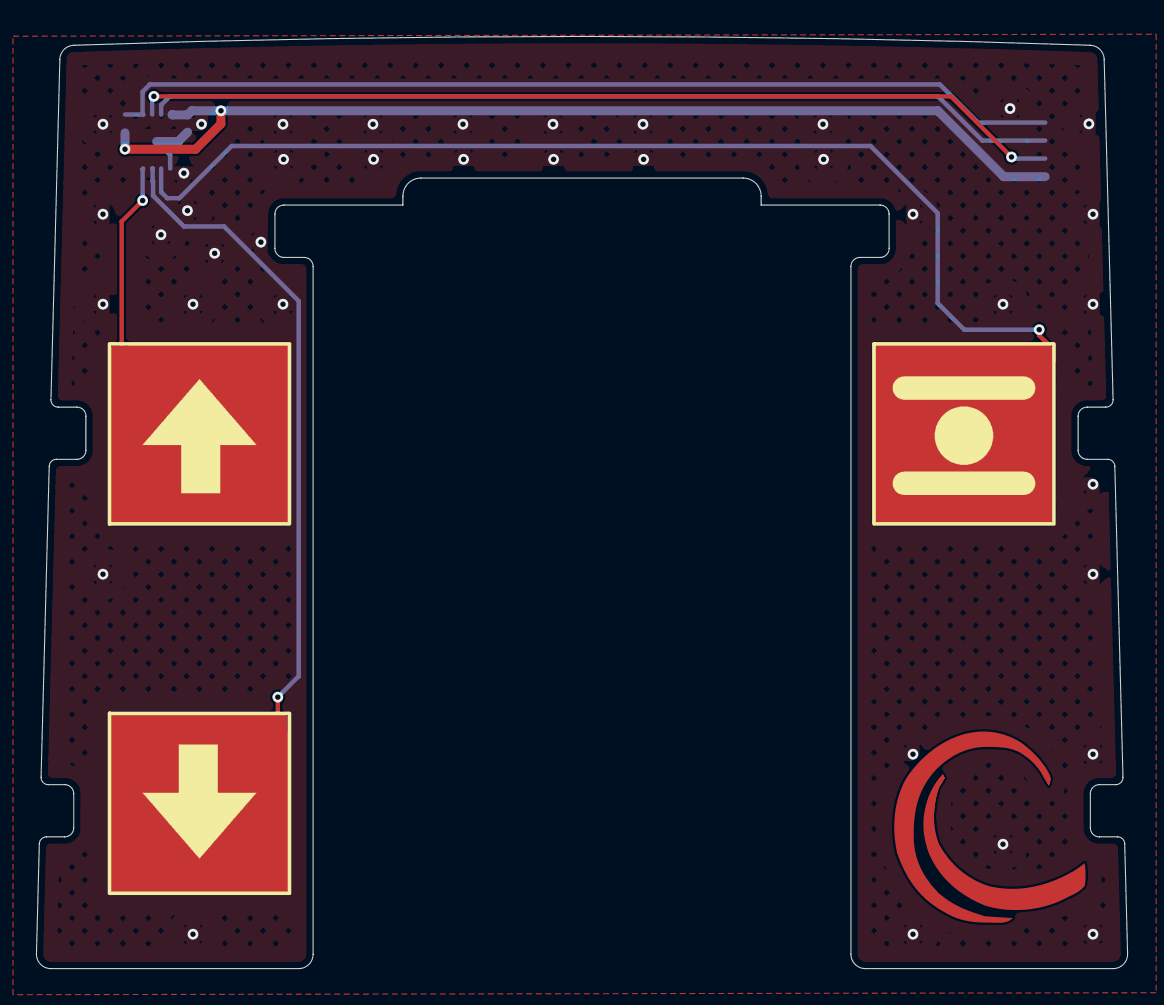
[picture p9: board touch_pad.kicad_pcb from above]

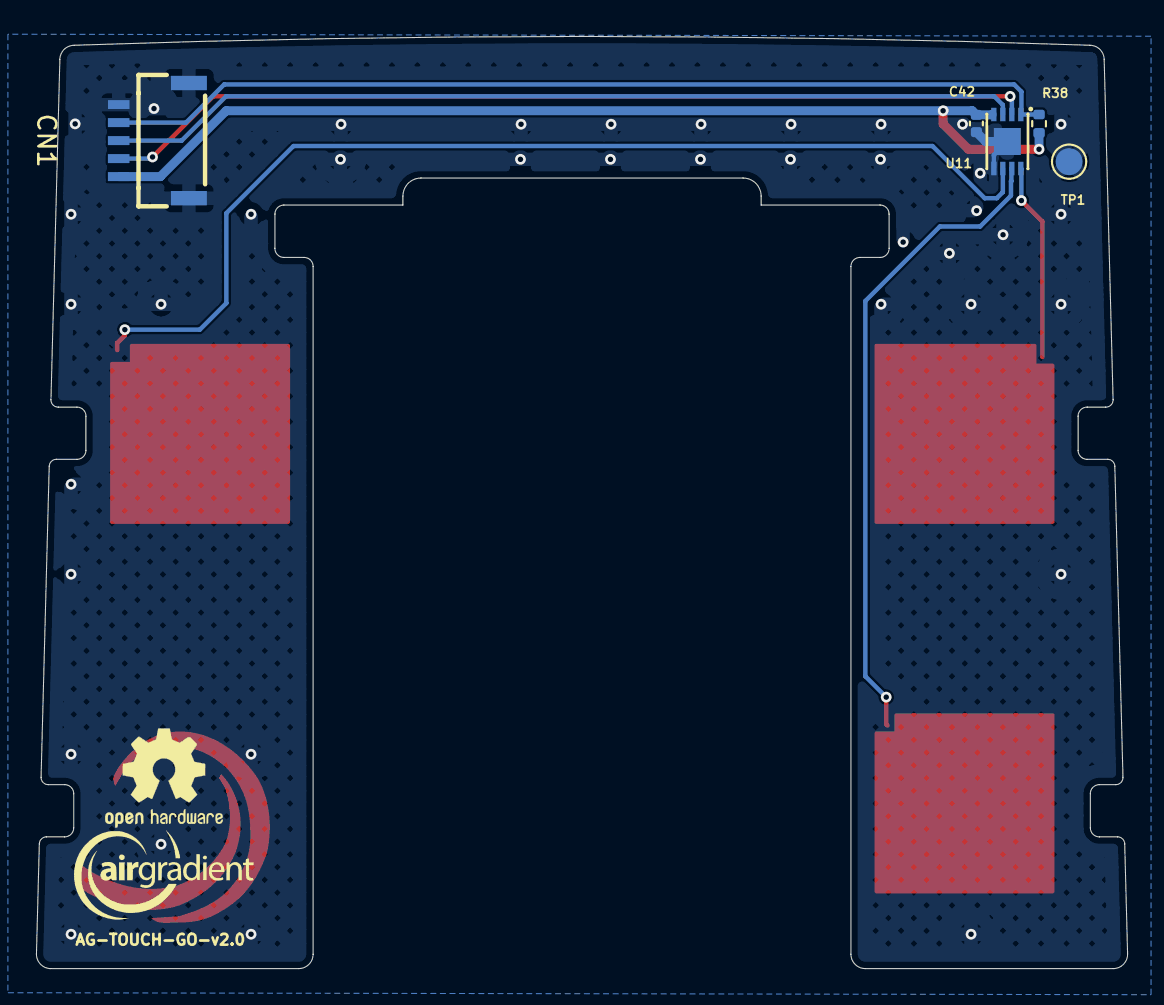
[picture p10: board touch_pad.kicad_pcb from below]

Board: 2 copper layers, 60.6 x 51.8 mm, 8 parts (5 on the bottom side), 8 nets.

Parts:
C42: 0.1uF/25V; C_0402_1005Metric
CN1: HCZZ0032-5; CONN-SMD_HCZZ0032-5
R38: 100K; R_0402_1005Metric
T1, T2, T3: tourch_pad
TP1: TestPoint; TestPoint_Pad_D1.5mm
U11: CAP1203-1-AC3-TR; TDFN-8_L3.0-W2.0-P0.50-BL-EP

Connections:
/INT: CN1.4, R38.1, U11.1 (~ALERT)
/SCL: CN1.3, U11.3 (SMCLK)
/SDA: CN1.2, U11.2 (SMDATA)
GND: C42.1, CN1.5, CN1.6, CN1.7, TP1.1 (1_1), U11.5 (GND), U11.9 (EP)
unnamed: T1.1 (1_1), U11.8 (CS1)
unnamed: T2.1 (1_1), U11.7 (CS2)
unnamed: T3.1 (1_1), U11.6 (CS3)
VCC: C42.2, CN1.1, R38.2, U11.4 (VDD)

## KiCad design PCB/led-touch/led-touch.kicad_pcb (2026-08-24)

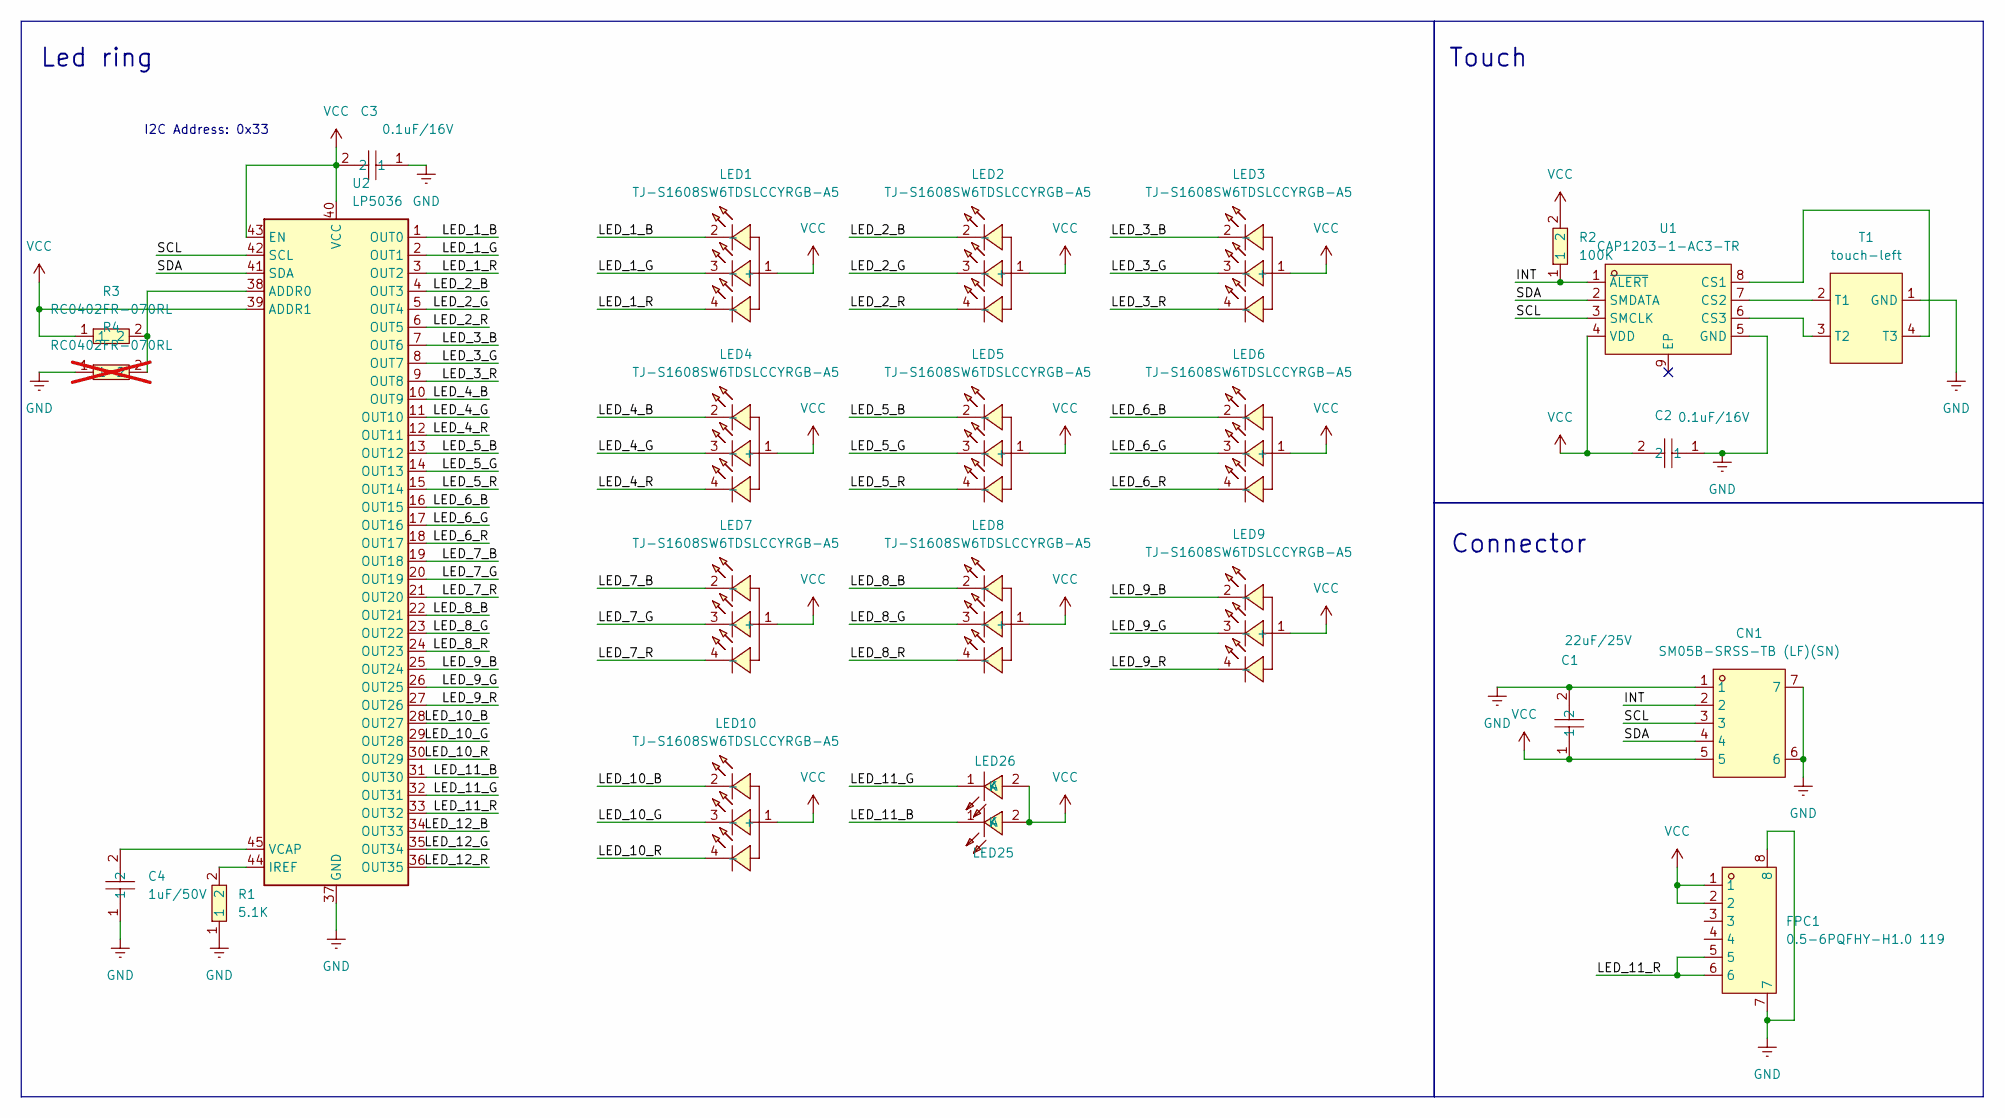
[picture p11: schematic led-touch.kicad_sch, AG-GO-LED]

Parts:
C1: 22uF/25V; C_0805_2012Metric; LCSC Part C602037
C2, C3: 0.1uF/16V; C_0402_1005Metric; LCSC Part C1525
C4: 1uF/50V; C_0402_1005Metric; LCSC Part C7500380
CN1: SM05B-SRSS-TB (LF)(SN); CONN-SMD_SM05B-SRSS-TB-LF-SN; LCSC Part C136657
FPC1: 0.5-6PQFHY-H1.0 119; FPC-SMD_6P-P0.50_0.5-6PQFHY-H1.0119; LCSC Part C2858296
LED1, LED2, LED3, LED4, LED5, LED6, LED7, LED8, LED9, LED10: TJ-S1608SW6TDSLCCYRGB-A5; LED-ARRAY-SMD_4P-L1.6-W0.8-BL-FD; LCSC Part C5356078
LED25, LED26: 99-213UMC/3640661/TR8-T; LED-SMD_L2.8-W1.2-RD; LCSC Part C181869
R1: 5.1K; R_0402_1005Metric; LCSC Part C105872
R2: 100K; R_0402_1005Metric; LCSC Part C60491
R3: RC0402FR-070RL; R_0402_1005Metric; LCSC Part C106231
R4: RC0402FR-070RL; R_0402_1005Metric; LCSC Part C106231; not fitted
T1: touch-left; touch-pad-go
U1: CAP1203-1-AC3-TR; TDFN-8_L3.0-W2.0-P0.50-BL-EP; LCSC Part C2652075
U2: LP5036; VQFN-46-1EP_5x6mm_P0.4mm_EP2.8x3.8mm

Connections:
/INT: CN1.2, R2.1, U1.1 (~ALERT)
/LED_1_B: LED1.2 (-), U2.1 (OUT0)
/LED_1_G: LED1.3 (-), U2.2 (OUT1)
/LED_1_R: LED1.4 (-), U2.3 (OUT2)
/LED_2_B: LED2.2 (-), U2.4 (OUT3)
/LED_2_G: LED2.3 (-), U2.5 (OUT4)
/LED_2_R: LED2.4 (-), U2.6 (OUT5)
/LED_3_B: LED3.2 (-), U2.7 (OUT6)
/LED_3_G: LED3.3 (-), U2.8 (OUT7)
/LED_3_R: LED3.4 (-), U2.9 (OUT8)
/LED_4_B: LED4.2 (-), U2.10 (OUT9)
/LED_4_G: LED4.3 (-), U2.11 (OUT10)
/LED_4_R: LED4.4 (-), U2.12 (OUT11)
/LED_5_B: LED5.2 (-), U2.13 (OUT12)
/LED_5_G: LED5.3 (-), U2.14 (OUT13)
/LED_5_R: LED5.4 (-), U2.15 (OUT14)
/LED_6_B: LED6.2 (-), U2.16 (OUT15)
/LED_6_G: LED6.3 (-), U2.17 (OUT16)
/LED_6_R: LED6.4 (-), U2.18 (OUT17)
/LED_7_B: LED7.2 (-), U2.19 (OUT18)
/LED_7_G: LED7.3 (-), U2.20 (OUT19)
/LED_7_R: LED7.4 (-), U2.21 (OUT20)
/LED_8_B: LED8.2 (-), U2.22 (OUT21)
/LED_8_G: LED8.3 (-), U2.23 (OUT22)
/LED_8_R: LED8.4 (-), U2.24 (OUT23)
/LED_9_B: LED9.2 (-), U2.25 (OUT24)
/LED_9_G: LED9.3 (-), U2.26 (OUT25)
/LED_9_R: LED9.4 (-), U2.27 (OUT26)
/LED_10_B: LED10.2 (-), U2.28 (OUT27)
/LED_10_G: LED10.3 (-), U2.29 (OUT28)
/LED_10_R: LED10.4 (-), U2.30 (OUT29)
/LED_11_B: LED25.1 (K), U2.31 (OUT30)
/LED_11_G: LED26.1 (K), U2.32 (OUT31)
/LED_11_R: FPC1.5, FPC1.6, U2.33 (OUT32)
/LED_12_B: U2.34 (OUT33)
/LED_12_G: U2.35 (OUT34)
/LED_12_R: U2.36 (OUT35)
/SCL: CN1.3, U1.3 (SMCLK), U2.42 (SCL)
/SDA: CN1.4, U1.2 (SMDATA), U2.41 (SDA)
GND: C1.2, C2.1, C3.1, C4.1, CN1.1, CN1.6, CN1.7, FPC1.7, FPC1.8, R1.1, R4.1, T1.1 (GND), U1.5 (GND), U2.37 (GND), U2.46 (GND), U2.47 (GND)
unnamed: T1.2 (T1), U1.7 (CS2)
unnamed: T1.3 (T2), U1.6 (CS3)
unnamed: T1.4 (T3), U1.8 (CS1)
unnamed: R3.2, R4.2, U2.38 (ADDR0)
unnamed: R1.2, U2.44 (IREF)
unnamed: C4.2, U2.45 (VCAP)
VCC: C1.1, C2.2, C3.2, CN1.5, FPC1.1, FPC1.2, LED1.1 (+), LED2.1 (+), LED3.1 (+), LED4.1 (+), LED5.1 (+), LED6.1 (+), LED7.1 (+), LED8.1 (+), LED9.1 (+), LED10.1 (+), LED25.2 (A), LED26.2 (A), R2.2, R3.1, U1.4 (VDD), U2.39 (ADDR1), U2.40 (VCC), U2.43 (EN)

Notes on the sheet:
I2C Address: 0x33
Touch
Connector
Led ring

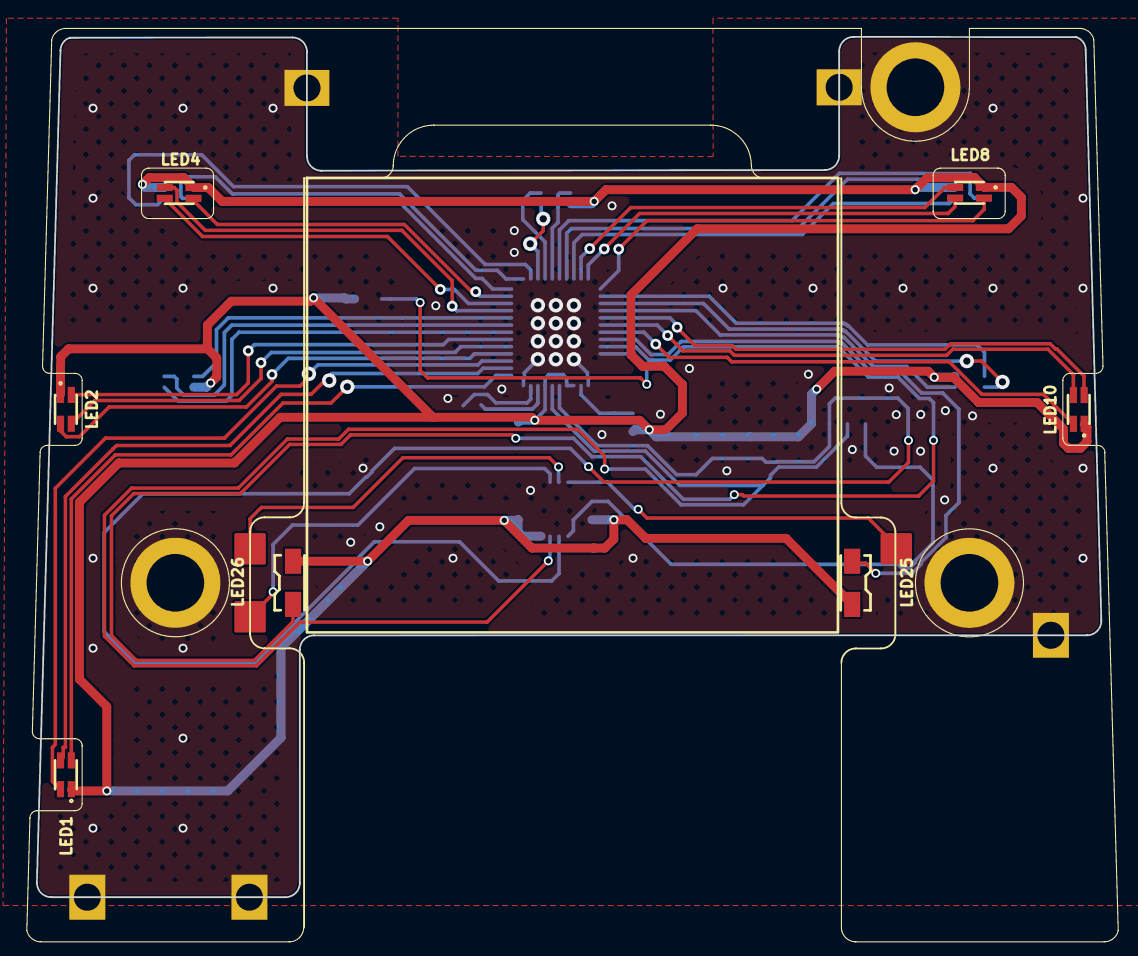
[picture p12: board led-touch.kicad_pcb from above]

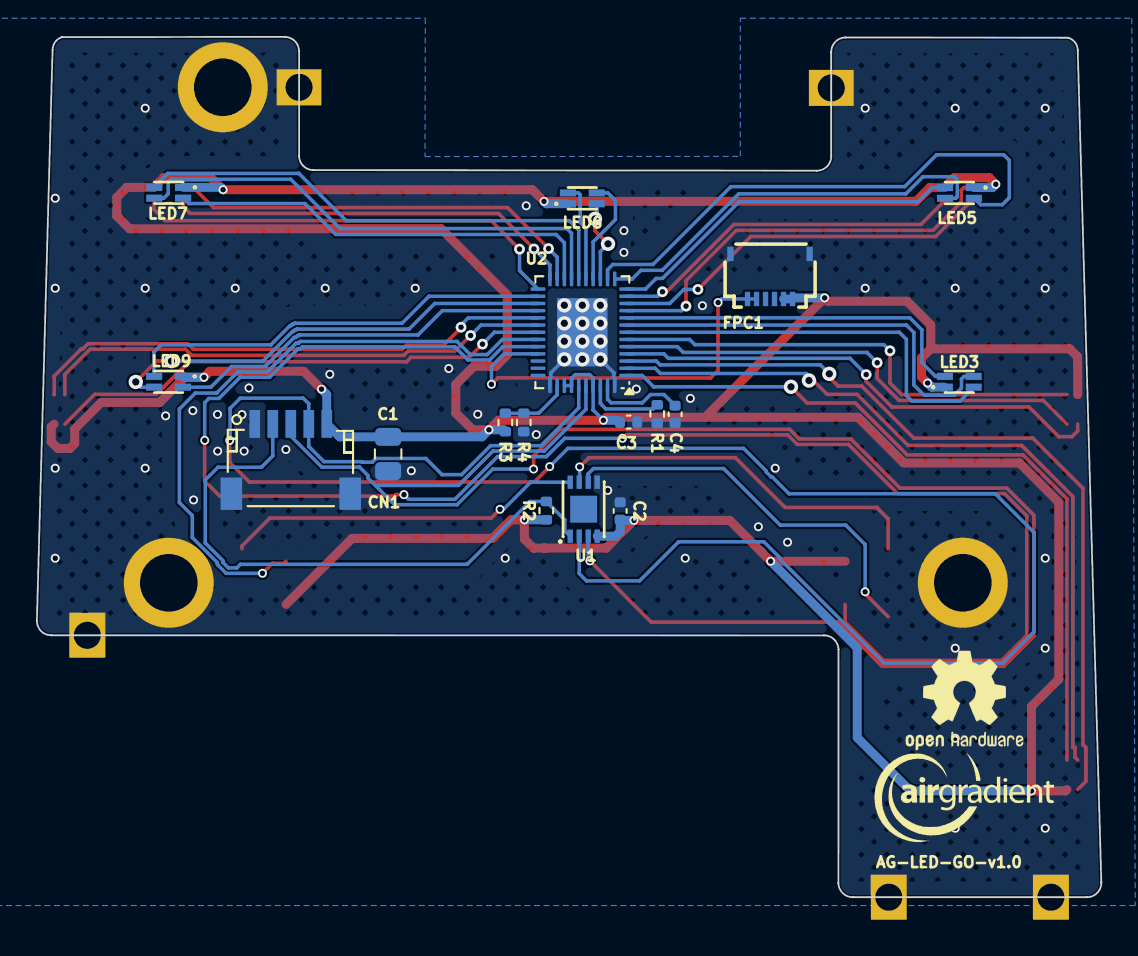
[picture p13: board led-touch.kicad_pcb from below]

Board: 2 copper layers, 59.1 x 47.8 mm, 26 parts (17 on the bottom side), 44 nets.

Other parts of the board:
EPAPER**: Epaper

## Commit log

2026-08-24 Initial import — AirGradient GO hardware (KiCad)
    Clean snapshot migrated from the Bitbucket repository (full history
    remains there). Contains the four KiCad projects under PCB/
    (airgradient-go-main v1.0, led-touch (AG-GO-LED) v1.0,
    touch-pad v1.0, scd4x-module v0.1), shared libraries/, graphics/,
    README, and CC BY-SA 4.0 license.
    [AG-GO-LED_1.0_bom.csv, AG-GO-LED_1.0_designators.csv, AG-GO-LED_1.0_positions.csv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]
2026-08-24 Import v2.0 development state from Bitbucket branch v2.0
    Overlay of the v2.0 design work onto the restructured PCB/ layout:
    - airgradient-go-main v2.0 WIP: 186 footprints, microSD, PS1-CO,
    Birdy schematic review fixes; adds v2.0 BOM CSVs
    - touch-pad v2.0: T1-T3 pads wired to touch controller CS channels,
    +3.1V rail renamed to VCC
    - scd4x-module: minor updates
    - libraries: new parts (SPL07-003, BM05B-SRSS-TB, PS1-CO, battery
    holder, ESP32-C5 models) and updated footprints; all library and
    3D model references normalized to ${KIPRJMOD}-relative paths
    - led_pcb board was dropped in v2.0 (never migrated)
    Known open items carried over from review: U14 VDD_IO not yet
    connected to the 3.1V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
    [SCD4x-module.kicad_pcb, SCD4x-module.kicad_sch, airgradient-go-bom-v2.0-LCSC.csv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]
2026-08-25 Rework main PCB layout: ESP32-C5 placement, routing, and silkscreen
    - Move ESP32-C5 module further inward from the board edge and rework affected track routing
    - Improve reference designator silkscreen placement
    - Restore SD card section (DNP)
    - Add OSHW and AirGradient logos and version label
    - Move Q5 closer to L3
    [Airgradient-GO_0.1_bom.csv, Airgradient-GO_0.1_designators.csv, Airgradient-GO_0.1_positions.csv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]
2026-08-25 Fix S12 footprint
    [airgradient-go-main.kicad_pcb]
2026-08-25 Schematic: - Change SPI pull-ups R2/R3/R14 from 10K to 100K - Connect C74 decoupling cap to +3.1V rail (was floating)
    PCB:
    - Narrow the board outline around the temperature sensor area
    - Move S12 0.3mm left and rework nearby I2C tracks
    [Airgradient-GO_0.1_bom.csv, Airgradient-GO_0.1_designators.csv, Airgradient-GO_0.1_positions.csv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]
2026-08-26 Create production files; switch touch pad connector to Hong Cheng
    Mainboard:
    - Export v2.0 production files (gerbers, BOM, positions) and 3D STEP model
    - Add BOM.csv export
    Touch pad:
    - Change CN1 connector manufacturer from JST to Hong Cheng HCZZ0032-5 (same housing)
    - Regenerate production files as v2.0 (BOM now includes full parts list)
    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
    [Airgradient-GO_2.0_bom.csv, Airgradient-GO_2.0_positions.csv, BOM.csv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]
2026-09-23 v2.1: post-prototype fixes from v2.0 review and issue #1
    - Battery: add C75 (100nF 0402) from BAT+ to GND at the battery +
    terminal as an RF shunt, with a GND via next to it
    - NTC1 moved next to the battery negative tab (B.Cu), part changed
    to NCP15XH103F03RC; BQ25628 TS divider R18/R19 = 5.23k/30.1k
    - Add R60 100K pull-up on TCA6408 RESET
    - BOM: fix LCSC part numbers that were shared across different values
    (R13 2K -> C4109, R5/R12 200R -> C25087, 100K group -> C60491,
    C17/C21/C27 corrected)
    - Remove test point footprints that were placed outside the board
2026-09-23 Bump board revision to 2.1 (title block, silkscreen)
2026-09-23 Move silkscreen references (C38, C75, NTC1, NTC2, R60)
2026-09-24 v2.1: switch 5-pin connectors to HCZZ0032-5, DNP SD card
    - CN1/CN2/CN3 are now HCZZ0032-5 (replaces SM05B-SRSS-TB CN3/CN4/CN5)
    - SD card not populated: TF1, R50-R58, C42, C71 set to DNP
    - BOM.csv regenerated
    Known issues (to fix before production):
    - CN2 pad 7 (GND) overlaps the /SCL trace on F.Cu (DRC short)
    - 6 footprint attribute mismatches vs schematic (exclude-from-BOM /
    DNP on AE1, BT1, U10, U11, U12, U18) - run Update PCB from Schematic
2026-09-28 Refill zones; set PCB title-block revision to 2.1
2026-09-28 touch-pad v2.1: revision and silkscreen to v2.1, add v2.1 production files
2026-11-13 v2.1: BOM matches the produced boards, CN2 short removed, add the 2.1 fab set
    The tag v2 files did not match what was built:
    - R18 5.23k and R19 30.1k still carried the LCSC numbers of the old
    values (C327340 = 4.12k, C851231 = 17.4k). Now C25907 and C29402, the
    parts the 1000-unit run used.
    - L3 value read XRTC201210S100MBCA; its part C39846618 is
    XRIM201210S100MBCA.
    - /SCL on F.Cu overlapped CN2 pad 7 (GND) by about 0.15 mm. JLCPCB
    patched the pad on the orders made from this board; the board file
    never had the fix. /SCL and /SDA now take the path branch
    v2.1-xtal32k gives them, 0.33 mm and 0.30 mm west. DRC errors 96 -> 94
    (the short and its solder-mask bridge), unconnected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
2026-11-13 README: describe v2 (main board 2.1): versions, boards, key parts with 2.1 references, production sets, parts without LCSC numbers
2026-11-13 Add hardware spec sheets for v2 (SPEC-SHEET.md) and v1 (SPEC-SHEET-v1.md); README links them
    Each sheet describes one version: sensors, radio, power, mechanical, and the parts the KiCad BOM does not define (display, battery, internal cables with pin maps). The v1 sheet is read from the schem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
2026-11-13 Add documents/: datasheets of the main parts and the manufacturers' documents for the display, the battery, the S12 and the GNSS antenna; CLAUDE.md and AGENTS.md for AI agents; README and both spec s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
